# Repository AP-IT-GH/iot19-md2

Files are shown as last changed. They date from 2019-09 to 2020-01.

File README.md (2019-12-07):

# Internet of Things - Medical delivery

## Groepsleden

Jarno Cools - Project Manager, Documentating and all-round  
Imad El-Azzouzi - PCB designer, Front-end Programmer and Professional Email Sender to Mr. Luyts         
Oussama Es-Salhi - Back-end Programmer / Systems integrator  
Cristian Baba - Front-end programmer / system testing and programming

## Documentatie

[Medical Delivery Analyse](/doc/analyse.md)

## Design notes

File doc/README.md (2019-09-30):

# Medical Delivery - Documentation

## Quick links

[Medical Delivery Analyse](/doc/analyse.md)

[Explenation electrical Scheme](/doc/electrical_scheme.md)

[Power consumption](/doc/power_consumption.md)

## Datasheets

In this folder you can find all the datasheets for the used components. If refered to a datasheet there will be a link to the datasheet in the markdown file.

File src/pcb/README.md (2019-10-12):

# PCBs

## MCU module

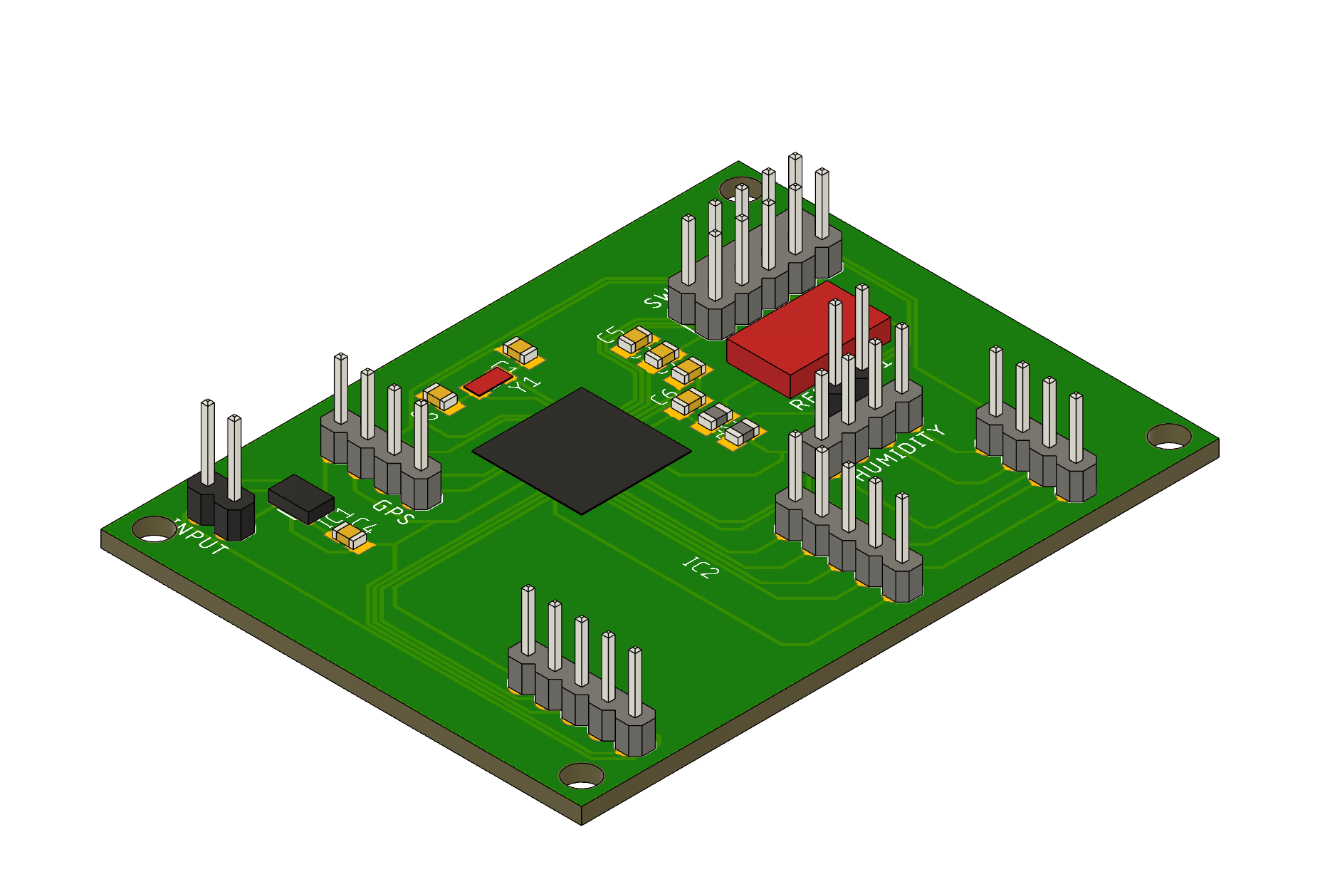
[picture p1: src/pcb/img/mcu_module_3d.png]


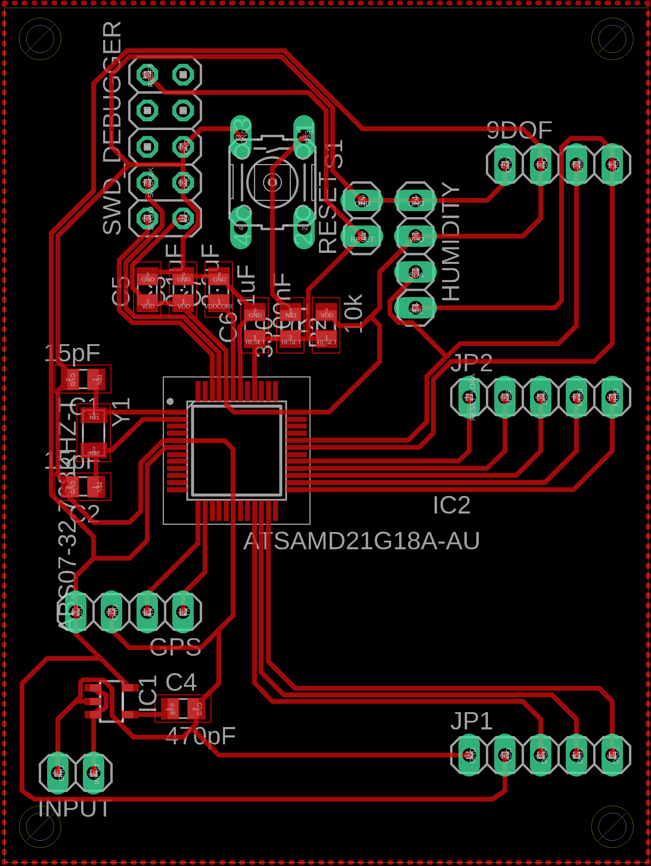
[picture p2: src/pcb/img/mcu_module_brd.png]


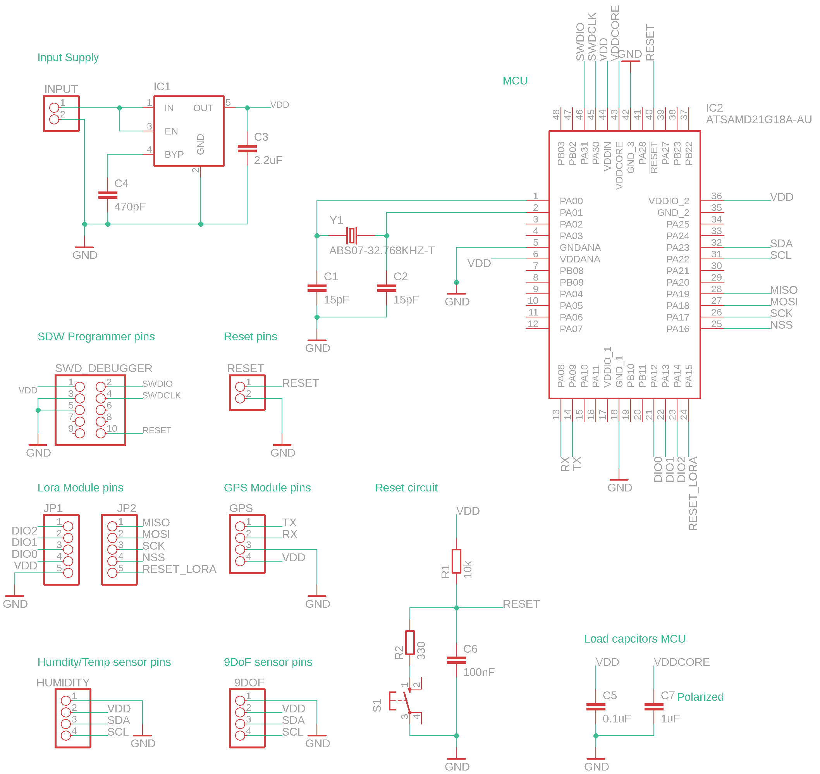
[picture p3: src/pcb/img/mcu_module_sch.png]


## LoRa module

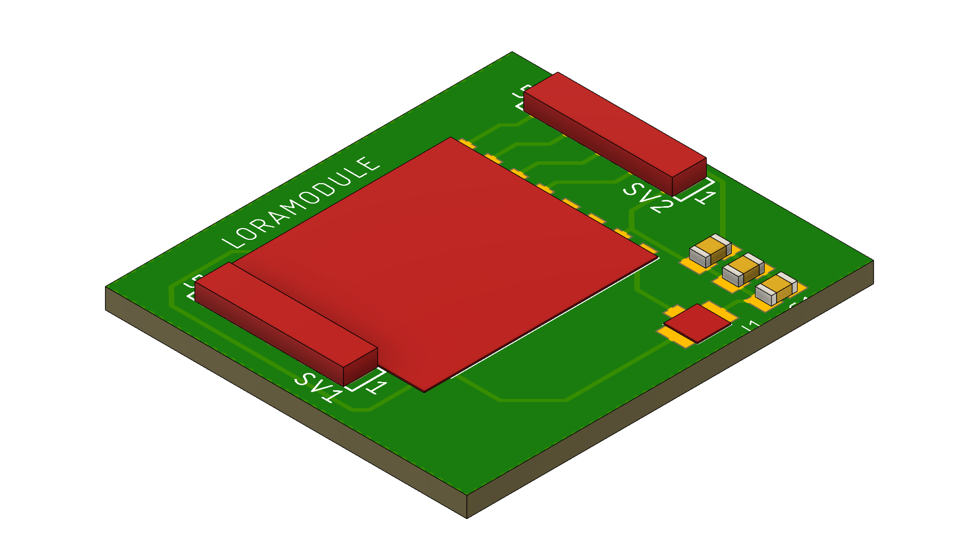
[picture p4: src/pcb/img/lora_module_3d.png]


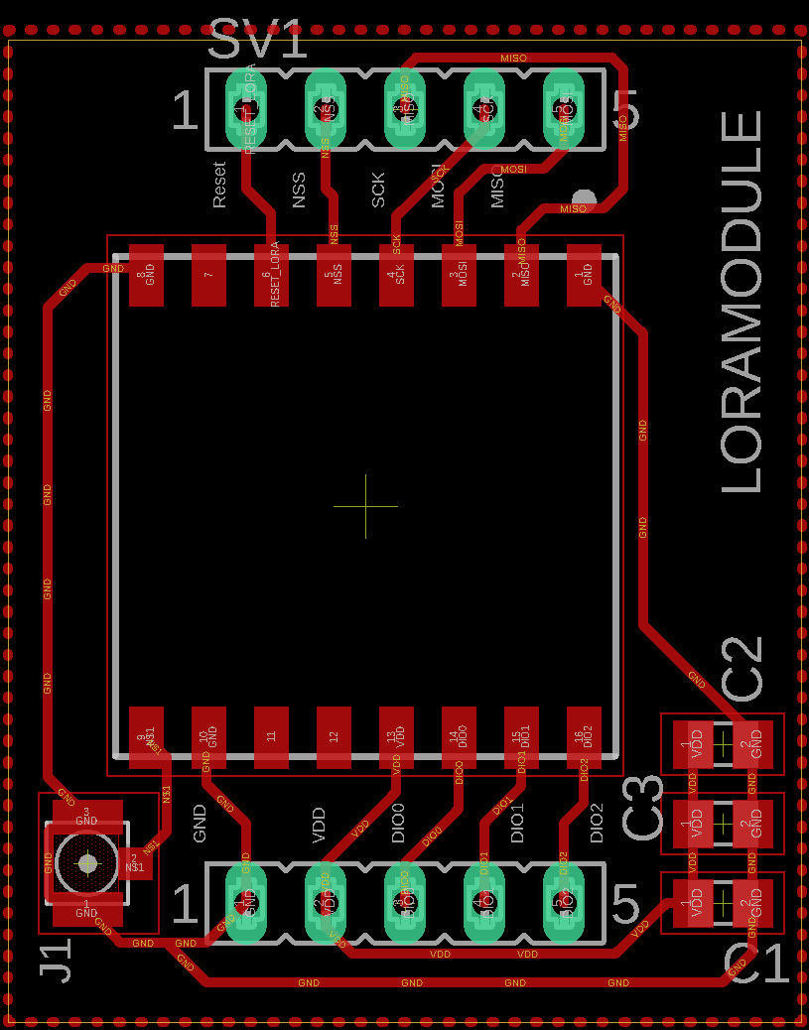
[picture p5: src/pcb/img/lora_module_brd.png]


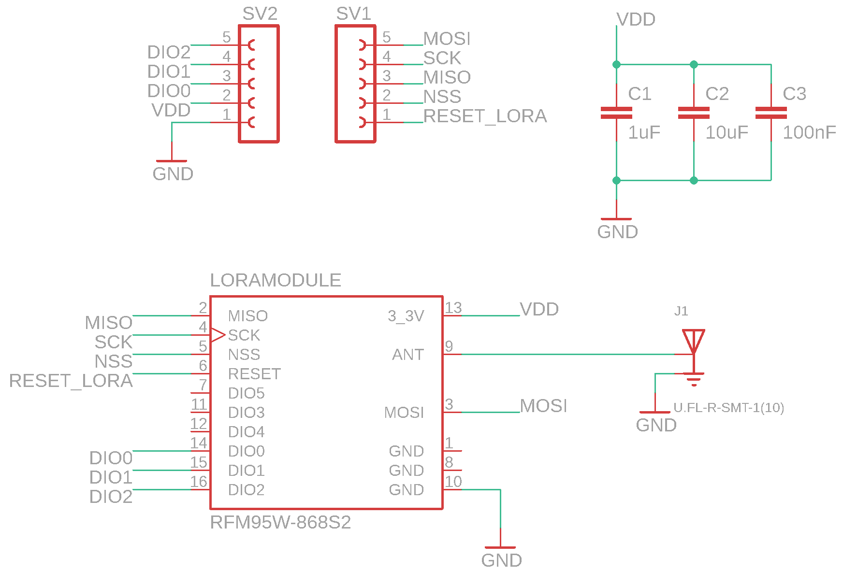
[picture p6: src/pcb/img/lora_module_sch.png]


## GPS module

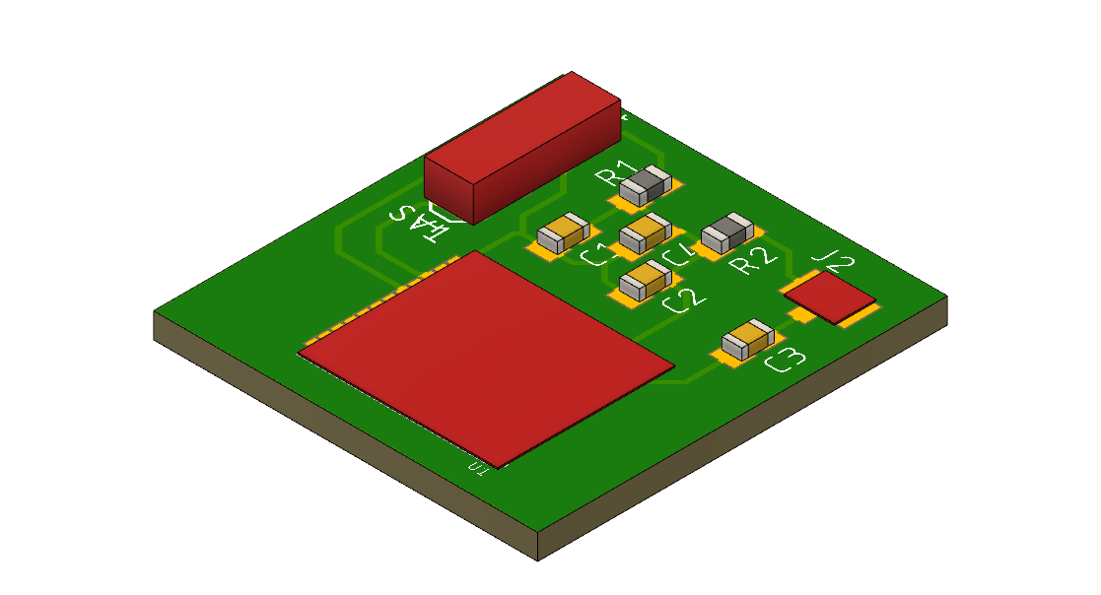
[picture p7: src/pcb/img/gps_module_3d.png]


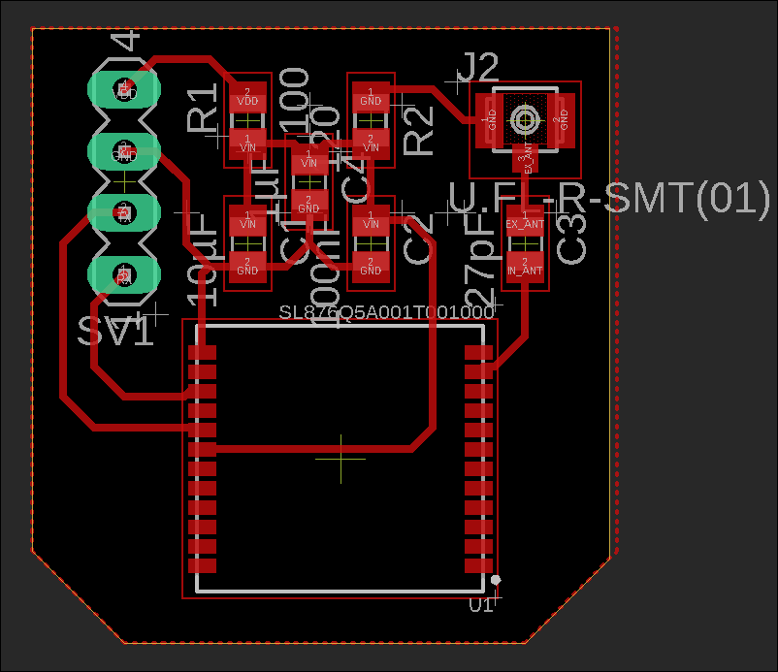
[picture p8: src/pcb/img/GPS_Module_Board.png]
Board


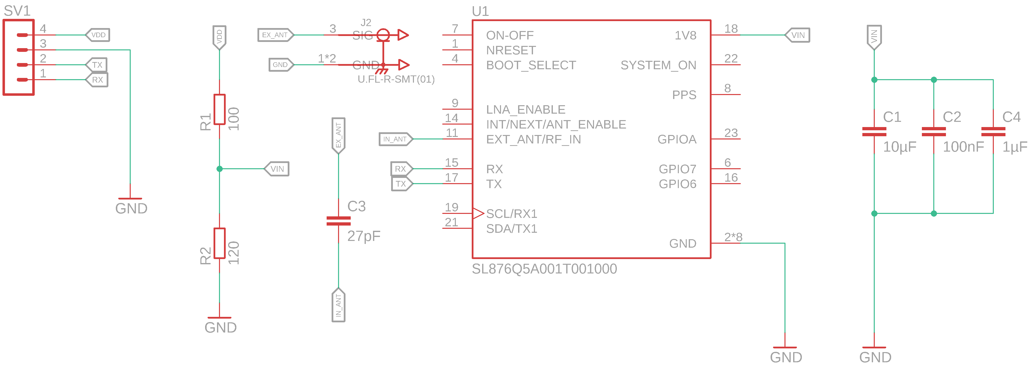
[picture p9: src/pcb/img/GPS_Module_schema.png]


## Humidity sensor

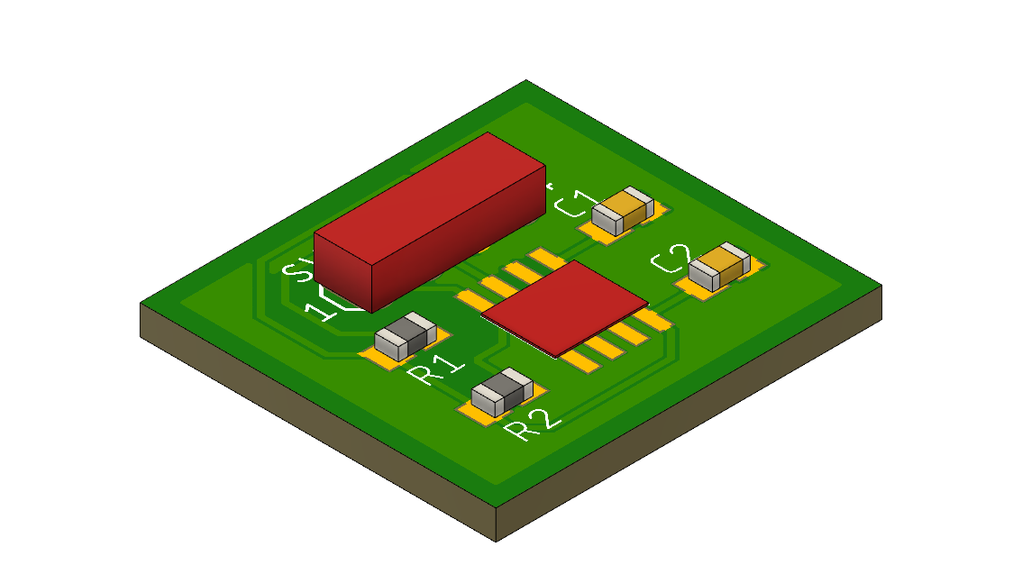
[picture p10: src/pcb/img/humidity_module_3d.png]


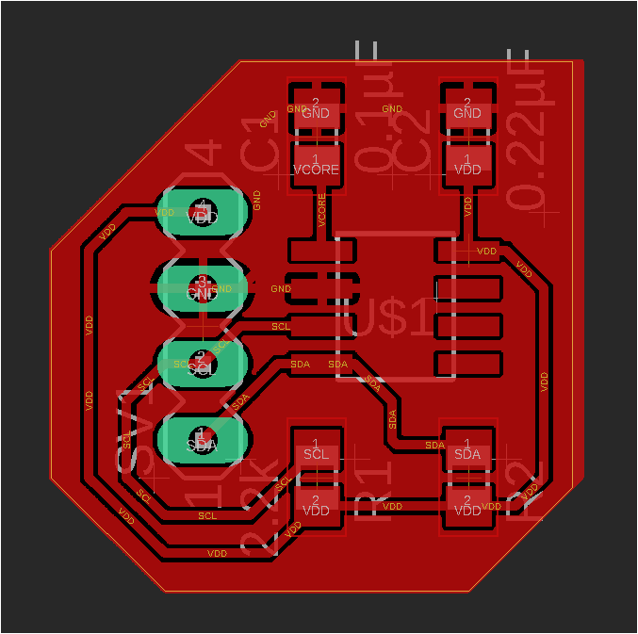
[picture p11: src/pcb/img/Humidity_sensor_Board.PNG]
Board


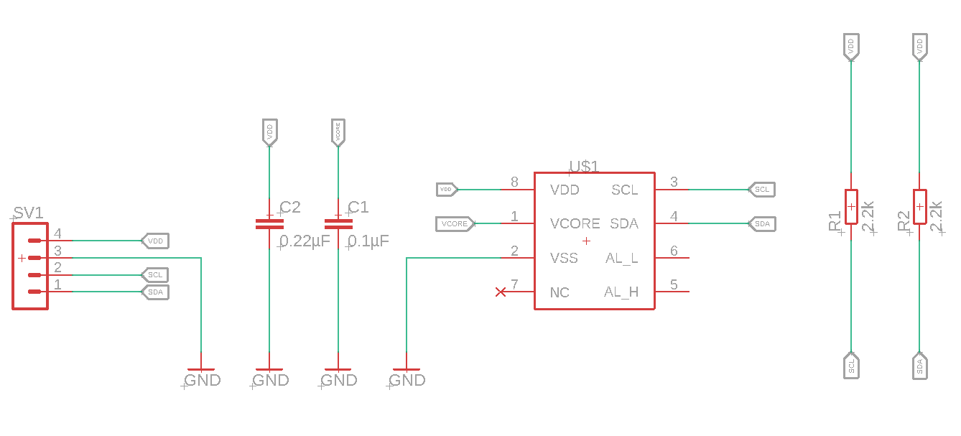
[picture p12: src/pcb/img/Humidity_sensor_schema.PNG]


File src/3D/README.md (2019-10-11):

# 3D objects

## m3_spacers_5mm.stl
This is the m3 mount for under the pcb.

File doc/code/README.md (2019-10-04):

# Code - Documentation

## Summary

The IDE used for this project is Atmel Studio 7. Programming to the MCU will be done via SWD programmer ATMEL ICE on the custom MCU module board [MCU Module](../src/pcb/img/mcu_module_3d.png). For testing code etc. before the custom board is printed and solderd the **Atmel SAMD21 XPlained PRO** board is used.

## Project init

Via the website of [Start Atmel](https://start.atmel.com/) you can initalize your project and basic settings like pin names.  
You start by choosing your IC/dev board. After choosing your IC/dev board you can add software components/drivers like for example Delay, DAC, etc. When you chose your drivers or if you didn't need any you can click on PINMUX. Here you can select a pin e.g. PA00/Pin 1 change the user label and the pin mode. After these steps you can export the project as an Atmel Project.

When exported you can import this in atmel studio as Atmel Start project. The project will have made a file **atmel_start_pins.h**.  
Here you can manually add pins as macros through (E.g. PA04):

```
#define PA04 GPIO(GPIO_PORTA, 4)
```

In the file **main.c** is where you write all you code.

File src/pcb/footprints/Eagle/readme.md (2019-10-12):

# Footprints - EAGLE

## ATSAMD21E18A-AF.lbr

Library for the ATSAMD21E.

## ATSAMD21G.lbr

Library for the ATSAMd21G.

## ABS07-32.768KHZ-T

Library for the crystal.

## S2B-PH-SM4-TB.lbr

Library for the input cable from the lithium battery.

## SL876Q5A001T001000

Library for the GPS module

## HIH6030-021-001

Library for the Humidity sensor

## U.FL-R-SMT_01_.lbr

Library for the U.FL (Male U.FL connector)

## RFM95W-868S2.lbr

Library for the LoRa module.

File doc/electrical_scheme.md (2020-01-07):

# 1. MCU Module PCB

## ATSAMD21

### Power supply

> ([Datasheet ATSAMD21](./datasheets/Atmel-42181-SAM-D21_Datasheet.pdf) p. 26, 7.2.3 and p. 1008, Table 38-1)  
> Power Supply Connection used is the typical Powering Schematic out of the datasheet.

### Externall Oscillator

> ([Datasheet ATSAMD21](./datasheets/Atmel-42181-SAM-D21_Datasheet.pdf) p. 1013, 38.6.3)

_Load capacitors calculation_

> CLtotal = (CL1 \* CL2)/(CL1+CL2) + CP  
> CL1=CL2= (CLtotal - CP) \* 2  
> CL = 12,5pF ([Datasheet ATSAMD21](./datasheets/Atmel-42181-SAM-D21_Datasheet.pdf) p.1013, Table 18-6)  
> CP = 5pF  
> CL1 = CL2 = (12,5pF - 5pF) \* 2 = 15pF

### Programmer SWD (Cortex Debug Connector)

> ([Datasheet ATSAMD21](./datasheets/Atmel-42181-SAM-D21_Datasheet.pdf) p. 1015, 38.7.1)  
> Program the MCU via SWD connection. 10 pin connector

> PA30 - SWDCLK  
> PA31 - SWDIO  
> RESET - RESET

## MIC5219-3.3YM5-TR

The voltage regulator of this project. Because MIC5219-**3.3** is used the fixed output is 3.3V.

Schematic used for the Fixed-Voltage version. ([Datasheet MIC5219](./datasheets/mic5219-3_3.pdf) p. 12, Figure 6)

### Connections to the IC

> ([Datasheet TPS735](./datasheets/tps735.pdf) p. 4, 5. Pin configuration)  
> Given all the connections for the pins, minimum and maximum values for capacitors.

### Reset circuit

The reset circuit has it's purpose to reset the MCU when the pin is triggered low. 2 header pins are added so if needed an externall reset controller could be added.

### Connections to the modules

All the sensor modules are given power through the MCU board every module has 2 extra pins for the GND and VDD(3.3V) pins.

#### LoRa Module pins

The connection between the MCU and the LoRa is SPI. Therefore the typical SPI pins are used MISO, MOSI, SCK and NSS. The reset pin from the LoRa module is connected with an DIO pin from the MCU so the MCU can reset the LoRa module. But when using the SAMD21 chips if the legacy SPI pins are not selected you'll have to create your own SPI connection [link to example](). Watch carefully in the datasheet which sercom is what en in the pinmapping of your library if the port is compatible.

> PA12 - DIO0       
> PA13 - DIO1       
> PA14 - DIO2           
> PA20 - RESET LoRa         
> PA19 - NSS        
> PA17 - SCK SERCOM1:[1] | ALT SERCOM3:[1]    
> PA16 - MOSI SERCOM1:[0] | ALT SERCOM3:[0]   
> PA18 - MISO SERCOM1:[2] | ALT SERCOM3:[2]   

#### GPS Module pins

The connection used for the GPS module is a simple serial connection (TX,RX).

> PA08 - RX  
> PA09 - TX

#### Humidity/Temp sensor pins

I2C is used between MCU and humidity sensor.

> PA22 - SCL  
> PA23 - SDA

#### 9DoF sensor pins

I2C is used between MCU and 9DoF.

> PA22 - SCL  
> PA23 - SDA

# GPS Module PCB

> ([Datasheet SE876Q5-A](./datasheets/Telit_SE876Q5-A_Datasheet.pdf))  
> ([gps_module_sch.png](../src/pcb/img/gps_module_sch.png))

### Power supply

> ([User Guide SE876Q5-A](./datasheets/Telit_SE876Q5-A_User_Guide.pdf) p. 34, 8.4.3 )  
> Capacitors are recommended with a minimum value of 10uF in parallel with a 0.1uF ceramic capacitor.

## Voltage divider

The voltage retrieved from the supply on the MCU's PCB is 3.3V. The maximum voltage of the GPS module is 1.8V. Therefore there is a voltage divider.

> Vout = I \* R2  
> I = Vin/(R1+R2)  
> Vout = Vin \* (R2/(R1 + R2))

Vin = 3.3V  
R2 = 120 Ohm and R1 = 100 Ohm

Vout = 1.8V

## SE876Q5-A

For this project is the serial port of the MCU used. So the TX from the GPS is connected to the RX from the MCU.
The TX from the MCU will be used for sending commands to the GPS.

# Lora Module RFM95W

## Antenna

An external antenna is required to transmit to and receive from the LoRa Gateway, an insulated copper wire is used with a length of 86mm.

The antenna length (L) is calculated as follow:

    c = λ x f
    L = ¼ x λ
    c = speed of light = 299792458 m/s
    λ = wavelength (m)
    f = frequency = 868000000 Hz (This frequency applies to Europe)
    L = antenna length (m)

    299792458 = λ x 868000000
    λ = 0.34538 m
    λ = 345.38 mm
    L = ¼ x λ = 86 mm (This antenna applies for Europe)

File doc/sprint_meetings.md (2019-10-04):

# Sprintmeetings

## Sprint 1

### Summarization of work

- Analyse gemaakt, elektrisch schema, componenten gekozen, release plan.
- Componenten informatie over vergaren, bedenken hoe te integreren met elkaar.
- Gekregen componenten veranderen door gekozen componenten, specificaties aanpassen in analyse en elektrisch schema aanpassen hiermee rekening houdend.

> Jarno: Analyse en documenteren. MCU PCB + elektrisch schema.  
> Imad: Analyse. Humidity en GPS PCB + schema.  
> Oussama: Analyse. MCU + LoRa module connecteren testen.  
> Cristian: Analyse. 9DoF sensor connecteren testen.

DONE:  
PCB's MCU, GPS and Humidty (Nog printen en solderen).  
First data from 9DoF.  
Able to upload simple program to MCU SAMD21 devboard.

User stories meenemen naar volgende sprint (niet helemaal af).

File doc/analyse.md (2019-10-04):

# Analyse

## Onderzoeksvraag

> Zijn producten nog bruikbaar na het transport door verschillende omstandigheden?  
> Hoe kunnen leveranciers weten dat ze tijdens transport moeten ingrijpen?  
> Wat moet er gebeuren indien producten onbruikbaar zijn geworden tijdens het transport?

## Voorstel tot oplossing

Medical delivery is een probleem in moeilijk bereikbare delen van de wereld. Er zijn veel omgevingen met schommelende temperaturen, van onder het nulpunt tot de brandende zon. Schokken tijdens het vervoeren van medische goederen kan de chemische structuur van de medicijnen aanpassen of andere pakketten onbruikbaar maken. Hierdoor bestaat er ook onzekerheid over herlevering.
Er is geen real-time informatie over de afstand en de staat van het product.

### Overzicht oplossing

Via real-time data kan men de locatie en de staat van het product nakijken. Een cross platform webapplicatie zal dit mogelijk maken. Indien een gebruiker het nodig acht om andere producten te laten brengen door een andere leverancier is dit mogelijk via de webapplicatie. De gebruiker zou de reeds bestelde producten kunnen annuleren indien deze niet meer aan de voorwaarden voldoen. Dan kan de transporteur terug gaan voor een nieuwe lading.

De mogelijkheid moet er ook zijn om alle producten onderweg op een kaart te zien, of de dozen in gebruik zijn en of deze aan het opladen zijn en waar deze gestockeerd staan. De hoeveelheid batterij resterend weergeven als je deze informatie opvraagt.

Per doos moeten er ook bepaalde specificaties ingesteld kunnen worden; bv. Hoeveel schokken kan deze doos aan, de maximum en minimum temperatuur, etc.

De leverancier moet producten kunnen kiezen welke hij meeneemt. Wanneer de leverancier een van de voorwaarden dreigt te overschrijden dient de webapplicatie op de smartphone/tablet een melding te geven zodat men hier tijdig op kan anticiperen.

#### Algemene architectuur

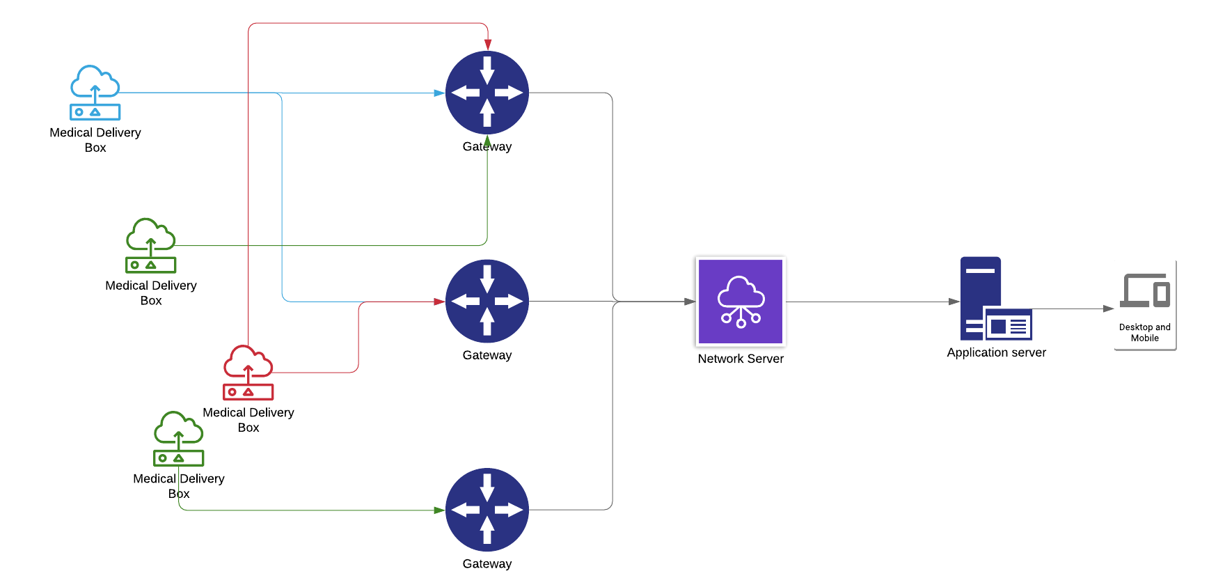
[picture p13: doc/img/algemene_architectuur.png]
Algemene architectuur

De verschillende boxen zullen als nodes werken en samen in een transportmiddel gestoken worden. Deze boxen sturen na een ingestelde tijdspanne data door indien er over de ingestelde grenzen is gegaan. De data wordt verstuurd naar LoRa Gateways. De sensor data die worden vergaard zijn oriëntatie, schokken, temperatuur, vochtigheid en positie. Aangezien het over afgelegen gebieden zou kunnen gaan waar geen LoRa gateway verbinding aanwezig zou zijn, kan er gebruikt gemaakt worden van een versterker zodat de reikwijdte vergroot wordt. De data zal gefilterd moeten worden via de end nodes zelf en enkel nodige data doorsturen.

## Marktonderzoek

| | Medicalcouriers | Hydropac | Worldcourier | Actioncourier | Zipline | TNT Healtcare section Supplies |
| --- | --- | --- | --- | --- | --- | --- |
| Sensors | ? | ? | Ambient temperature, internal temperature, light, tilt, pressureand physical shock sensors. | ? | ? | Ambient temperature and internal temperature sensors |
| Tracking | Tracking APP, Tracking center | / | GPS (Customer Resource Center (CRC) ) | Digital Log Tracking, GPS | 3D sattelite map and manual ground surveys | GPS |
| Temperature control | / | Can choose min and max of temperature | controls ambient an internal temperature | / | / | Realtime tracking of temprature |
| Communication protocol | / | / | BLE, GSM | / | SMS | / |
| App Control | Realtimedata, Dashboard | / | Realtime, monitoring | Monitoring | On-demand through a simple app, when they need it, monitoring, realtime data | Realtimedata, Monitoring |
| Transit time | / | Adjustable | / | Non-stop delivery | 30 - 45 min delivery | Sameday Delivery (ophaling en levering via de weg, na ophaling rechtstreekse levering bij de opgegeven ontvanger), Onboard courier ( zendingen die persoonlijke aandacht eisen), Air charter ( dringende zendingen ) |
| Type | Medical Courier | Insulated Shipping Systems | Medical logistics | Medical Courier serivce | Blood delivery by drone | Transport |
| Leveringen in | Washington, Oregon, Montana, Idaho, Wyoming, Californiä, Nevada, Utah, Arizona, New Mexico, Colorado, Oklahoma, Texas, Louisiana, Mississippi, Georgia, Alabama, Florida, North Carolina, Iowa, Minnesota, Wisconsin, Illinois, Michigan, Kentucky, Ohio, Indiana, Pennsylvania |  UK | Europa, North America, Asia PAcific, Latin America, Middle East, Africa |Oklahoma, Texas, Louisiana, Mississippi, Georgia, Alabama, Florida, North/South Carolina, Iowa, Minnesota, Wisconsin, Illinois, Michigan, Kentucky, Ohio, Indiana, Pennsylvania, Arkansas, Tennessee, Missouri, Virginia-West Virginia, Maryland, Delaware, New Jersey, New York, Connecticut, Massachusetts, Rhode Island, Maine, New Hampshire, Vermont | Rwanda & Ghana |Europe, Asia, Middle East, US|
| Website | [Website](https://www.medicalcouriers.com/) | [Website](https://hydropac.co.uk/#medi) | [Website](https://www.worldcourier.com/) | [Website](https://actioncourier.com) | [Website](https://flyzipline.com/) | [Website](https://common.tnt.com/express/en_xx/site/home/services/industry_sol/healthcare/pharmasafe.html) |

## Detail analyse

#### Blokdiagram

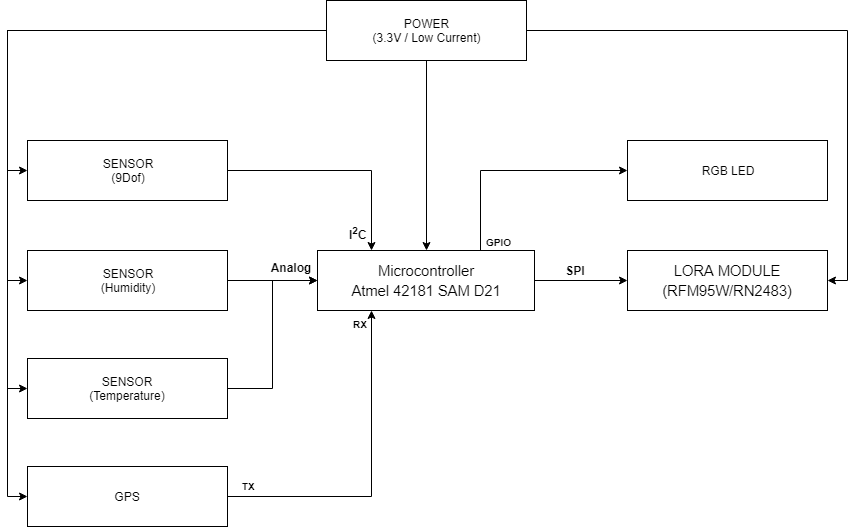
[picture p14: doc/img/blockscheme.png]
Mockup


##### Specificatietabel

| Blok | Specificatie | Min | Nominaal | Max |
| --- | --- | ----- | --- | ----- |
| Atmel SAM D21 | Werkspanning | 1.62V | | 3.63V |
| | Low-power verbruik | | <70 µA/MHz | |
| RFM95W | Werkspanning | 1.8V  | | 3.7V  |
| Lithium batterij | Spanning | | 3.7V | |
| | Capaciteit | | 2000mAh | |
| Telit SL876Q5-A GPS | Werkspanning | 1.71V | | 1.89V |
| | Stroomverbruik signal acquisition | | 85mW | |
| | Stroomverbruik tracking | | 83mW | |
| | Horizontale positie nauwkeurigheid| | 1.5m | |
| | Snelheid nauwkeurigheid | | 0.01 m/s | |
| | Richting nauwkeurigheid | | 0.01 deg | |
| HIH8120-021-001 TEMP HUM | Werkspanning | 2.3V  | 3.3 | 5.5V  |
| | Temperatuur range | -40°C | | 125°C |
| | Temperatuur nauwkeurigheid | | ±0.8 | |
| | Humidity range | 0RH | | 100RH |
| | Humidity nauwkeurigheid | | ±2.0 %RH | |
| | Sleep current | | 0.6µA | 1µA |
| | Supply current (I²C) | | 0.65mA | 1mA |
| IMU 9DOF v2.0 | Werkspanning | 2.4V  | | 3.6V  |
| MIC5219-3.3YM5-TR | Werkspanning | 2.5V  | | 12V  |
| | Uitgangspanning | | 3.3V | |
| | Stroomverbruik | 0 | | 500mA |
| | Temperatuur range | -40°C | | 125°C |
| Q13MC30610003 MC-306 | Frequency range | 20kHz | 32.768kHz  | 165kHz |
| | Laad Capaciteit | | 12.5pF | |
| | | | | |

##### Argumentatietabel

| Blok | Argumentatie | Alternatieven |
| --- | --- | --- |
| Microcontroller | Atmel SAM D21G gekozen omdat deze low power is. Heeft tot 6 Serial Communication Modules (SERCOM) dat elk geconfigureerd kunnen worden als een USART, UART, SPI of I²C. | ATmega328p |
| GPS | Er wordt gebruik gemaakt van de Telit SL876Q5-A GPS module van Telit deze module gebruikt relatief weinig vermogen (83mW - 85mW) en heeft verschillende modi die energie kunnen besparen. Ook heeft hij een hogere update rate van 10 Hz. Deze module ondersteund zowel GPS als GLONASS waardoor er meer satellieten zijn voor een nauwkeurige positie. | NEO-6M, BN-280 |
| LoRa module | RFM95W werd gekozen omdat deze aanzienlijk minder stroom verbruikt dan concurrerende modules. De hoge sensitiviteit met de +20dBm eindversterker levert een industry leading link budget op, waardoor het optimaal is voor elke toepassing die bereik of robuustheid vereist. | RN2483 |
| Temperatuur / Humidity sensor | De Honeywell 2-in-1 temperatuur- en vochtigheidssensor is nauwkeurig tot 0.8°C, 2.0 %RH en heeft een temperatuur range van -40°C tot 125°C. Door deze sensor te gebruiken wordt er pcb oppervlakte bespaart. De I2C output zorgt voor een makkelijkere integratie met de microcontroller. |  LMT87, LM35, MCP9700 |
| IMU 9DOF v2.0 | Ultra-low power, low voltage. Heeft een wide detecting range. | 9DoF Sensor Stick |

#### Elektrisch schema

Flowchart
[Elektrisch Schema](./electrical_scheme.md)
#### State Diagram

#### Flowchart

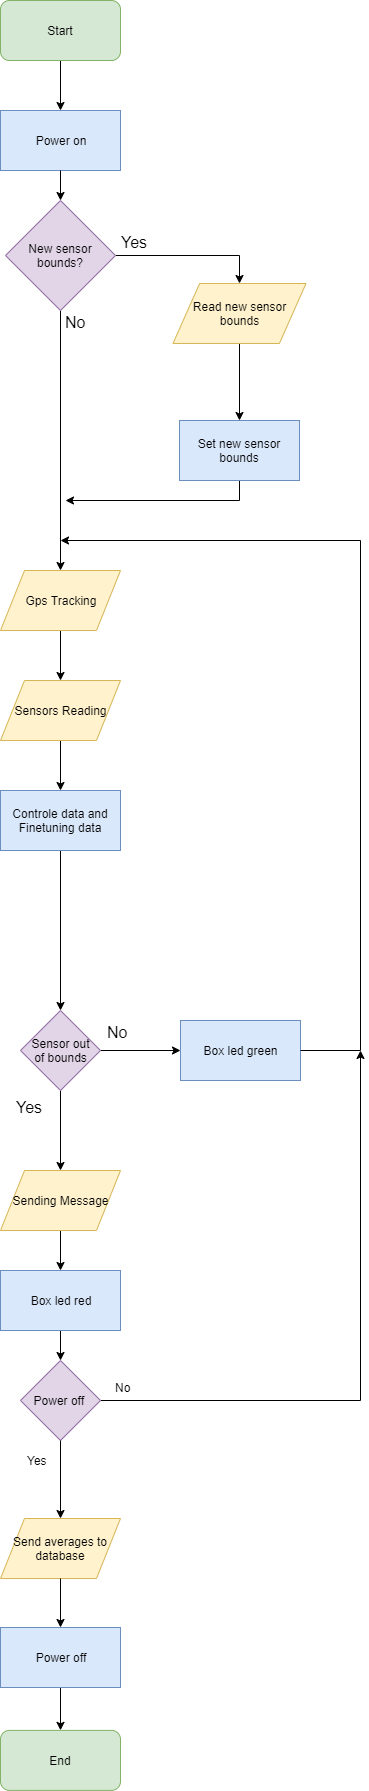
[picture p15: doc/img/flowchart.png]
Flowchart


### Front End

Mockup

### Back End

Er wordt gebruik gemaakt van firebase als "back end" dit omdat het makkelijk is om te scalen. De realtime database is ook een troef van Firebase waardoor de data in real-time wordt verstuurd naar de app of webapp wat aangenamer is voor de eindgbruiker.

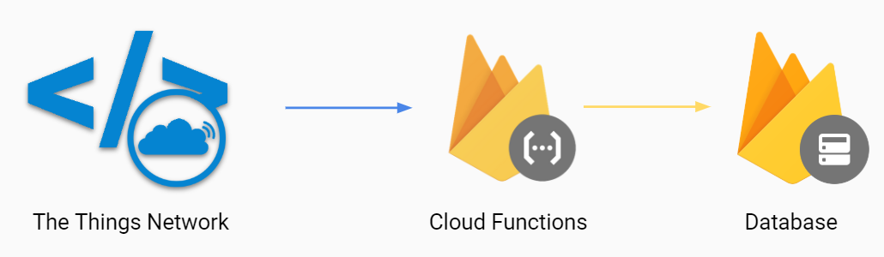
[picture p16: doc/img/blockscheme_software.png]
Software blockscheme


#### Database Model

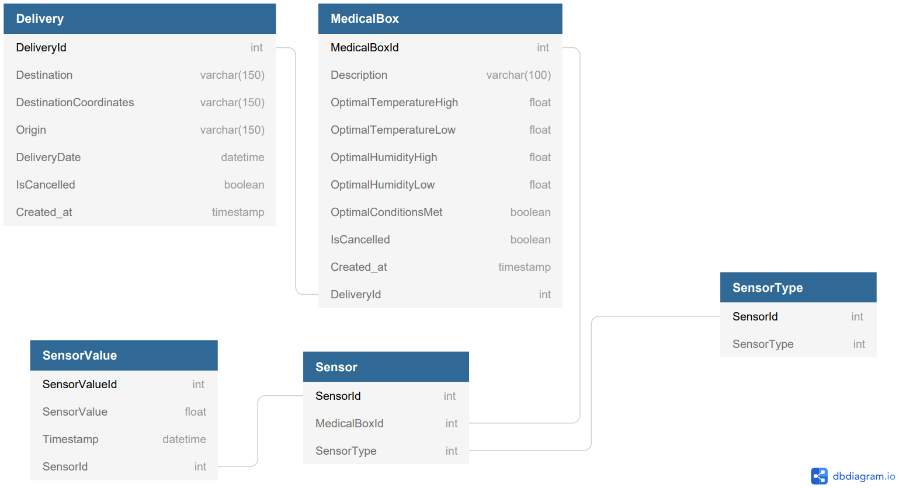
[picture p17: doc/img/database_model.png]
Database Model


## Niet functionele analyse

## Release plan

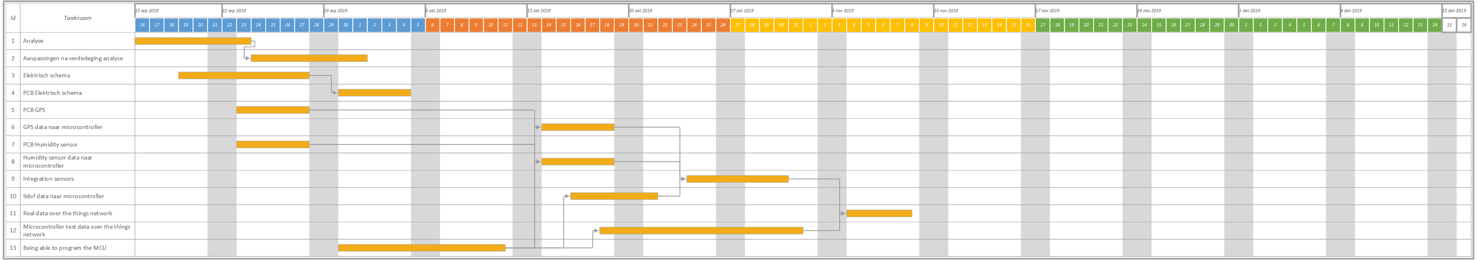
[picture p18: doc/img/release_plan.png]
Release plan sprint 1-2


## Inventarisatie Hardware

- Atmel SAM D21E - Microcontroller
- RFM95W - LoRa Module
- Telit SL876Q5-A - GPS Module
- HIH8120-021-001 - Temperature/Humidity sensor
- IMU 9DOF v2.0 - 9DoF
- MIC5219-3.3YM5-TR - Voltage regulator
- Lithium battery

[Bill of materials](./Bill_of_materials.pdf)

## Inventarisatie software

- AtmelStudio
- Angular
- Firebase

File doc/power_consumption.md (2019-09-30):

# Power consumption

De engerie die verbruikt wordt door alle componenten samen zou door de power supply een x-aantal uur geleverd moeten kunnen worden. Het berekenen van de consumptie gaat als volgt.
Vermogen W (**P = U \* I**) van dit vermogen wordt Wh genomen (**Wh = W \* h**). Hierna wordt er mAh berekend **mAh = 1000 \* Wh / V**. Deze mAh is nodig omdat batterij capaciteit in mAh is.

### Atmel SAMD21E

> (Datasheet Atmel SAMD21)  
> When the CPU is running a Fibonacci algorithm at 3.3V (25°C). The max. power consumption is 4.6mA.

- P = U \* I => P = 3.3V \* 4.6mA = 0.01518W
- Wh = 0.01518Wh (t = 1h)
- mAh = 1000 \* 0.1518Wh/3.3V = 20mAh

### HONEYWELL - HIH8120-021-001 TEMP HUM

> (HONEYWELL DATASHEET)
> -Via I2C is het verbruik gewoonlijk 0.65 mA

- P = U \* I => P = 3.3V \* 0.65mA = 0.002145W
- Wh = 0,002145 Wh
- mAh = 1000 \* 0.002145 Wh/3.3V = 0.65mAh

### Telit SL876Q5-A GPS

> (Telit Datasheet )

- Current consumption: ( GPS+GLO)
- Acquisition: 85mW
- Tracking: 83 mW

> Low power modes

- Hibernate: 69 uW
- SG1 mode: 47-56mW
- HPR mode: 24-27mW

- Verbruik = 83 Mwh
- wh = 0.083Wh (watt hour)
- mAh = 1000 \* 0.083Wh/3.3V = 25.15mAh

### Voltage regulator - TPS73533DRVT

> TPS73533DRVT Datasheet

- Verbruik 45-μA (typical)
- P = U \* I => P = 3.3V \* 45μA = 0.0001485‬W
- wh = 0.0001485‬Wh
- mAh = 1000 \* 0.0001485‬Wh /3.3V = 0.045‬mAh

### Crystal Oscillator

> (Datasheet)

- Verbruik +- 100µW
- Wh = 0.0001 Wh
- mAh = 1000 \* 0.0001‬Wh /3.3V = +- 0.33mAh

### LMT87

> (Datasheet)

- Verbruik 6.6μA
- P = U \* I => P = 3.3V \* 6.6μA = ‬0.00002178W
- Wh = 0.00002178 Wh
- mAh = 1000 \* 0.00002178 Wh /3.3V = 0.066mAh

### IMU 9DoF v2.0

> (Datasheet)

- 9-axis (no DMP), 1 kHz gyro ODR, 4 kHz accel ODR, 8 Hz mag. repetition rate
- 4,9 mA
- P = U \* I => P = 3.3V \* 0.049A = 0,1617‬W
- Wh = 0.1617‬ Wh
- mAh = 1000 \* 0.1617‬ Wh /3.3V = 49 mAh

### RFM95W

> (Datasheet RFM95 p.13 2.4.1)  
> IDDT supply current when transmitting is 120mA.

- P = U \* I => P = 3.3V \* 120mA = 27,5W
- Wh = 0.01518Wh (t = 1h)
- mAh = 1000 \* 0.1518Wh/3.3V = 20mAh

## Totale verbruik

- mAh(totaal) = 20mAh + 0.65mAh + 25.15mAh + 0.045mAh + 0.33mAh + 49mAh + 20mAh = 115.175mAh

Het aantal uren voordat de batterij leeg is:

- Capaciteit / Totale Verbruik => 2000mAh / 115.175mAh = 17.36 Uur

_\*Opmerking: In deze berekening is er geen rekening gehouden met het feit dat de LoRa module niet continu gaat uitzenden en de mogelijke optimalisatie van het verbruik van de verschillende componenten. Dit betekent dat het totale verbruik behoorlijk lager zal liggen._

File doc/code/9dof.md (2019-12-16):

# LoRa The Things Network Code Documentation

## Getting started

The 9DoF stick is connected via I2C to the microcontroller.

To install this library:

- Install it using the Arduino Library manager ("Sketch" -> "Include Library" -> "Manage Libraries...")
- download a zipfile from github using the "Download ZIP" button and install it using the IDE ("Sketch" -> "Include Library" -> "Add .ZIP Library..."
- clone the git repository into your sketchbook/libraries folder

  [Download Link LSM9DS1 Library](https://github.com/sparkfun/SparkFun_LSM9DS1_Arduino_Library/archive/master.zip)

## Sketch

In __LSM9DS1_Basic_I2C.ino__ you can see an example setup of some code that prints the 9DoF stick data.

As an example ```imu.calcAccel(imu.az)``` this shows the amount of force when moving up or down. This gives a digit back in the sketch they refer to it as G. In the graph you can see that we there were somet tests done. The peaks going up over 1.5 are forces going upwards (9DoF stick moving upwards). The others peaks going down under 0.5 are forces going downwards (9DoF stick moving downwards). In resting position the G-force is around 1 (G-force from the earth around 9.8m/s^2).

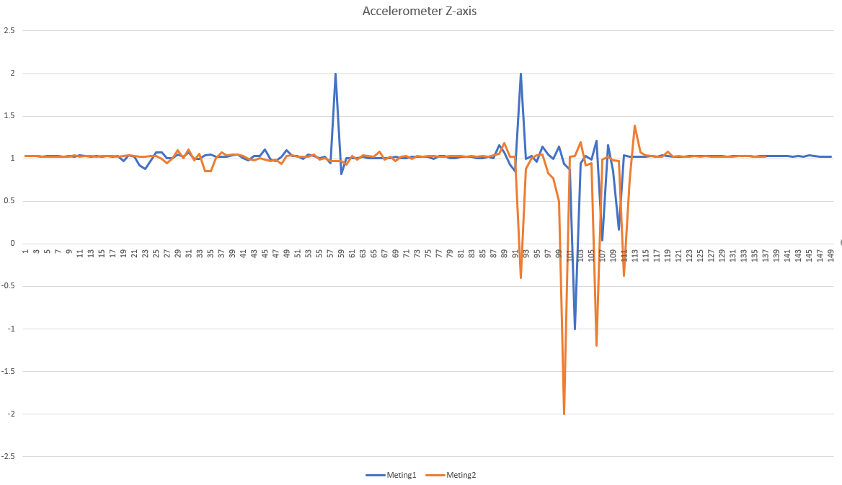
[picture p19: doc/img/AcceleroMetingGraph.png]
Accelro graph


## Integration LoRaWAN & 9DoF

For the integrations there were chosen some set boundaries. We send every out of boundaries a payload over the LoRa network. The payload was the highest/lowest value of the peak.

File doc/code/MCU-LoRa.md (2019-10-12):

# LoRa The Things Network Code Documentation

## Getting started

To communicate with the LoRaWAN network via the RFM95W module the "arduino-lmic" library is used.

To install this library:

- Install it using the Arduino Library manager ("Sketch" -> "Include Library" -> "Manage Libraries...")
- download a zipfile from github using the "Download ZIP" button and install it using the IDE ("Sketch" -> "Include Library" -> "Add .ZIP Library..."
- clone the git repository into your sketchbook/libraries folder

  [Link to arduino-lmic github repo](https://github.com/matthijskooijman/arduino-lmic)

## Library configuration

Open this file in your code editor: C:\Users\\\<username>\\Documents\Arduino\libraries\arduino-lmic-master\src\lmic\config.h

Make the following changes and save:

- set: #define CFG_eu868 1 (EU only)
- set: #define CFG_sx1276_radio 1
- set: #define LMIC_DEBUG_LEVEL 2 and #define LMIC_FAILURE_TO Serial
- Uncomment line: #define DISABLE_PING
- Uncomment line: #define DISABLE_BEACONS

## Using ttn-abp example sketch

To test the module and TTN integration an example sketch can be used.  
Load this sketch up in the arduino IDE by going to "File" -> "Examples" -> "LMIC-Arduino" -> ttn-abp (Activation-by-personalisation)

There are a couple things that need to be changed before uploading the sketch.

Copy the Network Session Key in constant variable:  
&nbsp; &nbsp; static const PROGMEM u1_t NWKSKEY[16] = { 0x1F, 0x42, 0x97, 0x73, 0xAE, 0xEA, 0xDA, 0xE8, 0xD4, 0xEE, 0x45, 0xF7, 0x54, 0xD4, 0xAE, 0x57 };

Copy the App Session Key in constant variable:  
&nbsp; &nbsp; static const u1_t PROGMEM APPSKEY[16] = { 0x96, 0x74, 0x6C, 0x57, 0xD8, 0xE3, 0xB1, 0xD6, 0x3A, 0x04, 0x83, 0x04, 0xC4, 0x56, 0x8D, 0x36 };

Copy the Device Address in constant variable:  
&nbsp; &nbsp; static const u4_t DEVADDR = 0x43984832;

Change the pinmap object:  
const lmic_pinmap lmic_pins = {  
&nbsp; &nbsp; &nbsp; &nbsp; .nss = 10,  
&nbsp; &nbsp; &nbsp; &nbsp; .rxtx = LMIC_UNUSED_PIN,  
&nbsp; &nbsp; &nbsp; &nbsp; .rst = 5,  
&nbsp; &nbsp; &nbsp; &nbsp; .dio = {2, 3, LMIC_UNUSED_PIN},  
};

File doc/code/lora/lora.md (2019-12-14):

# LoRa the things network
## LoRa RFM95W library

In dit project is er gebruik gemaakt van de arduino-lmic [library](https://github.com/matthijskooijman/arduino-lmic).

Echter omdat er gewerkt werd met een SAMD21 en de legacy SPI pins niet gekozen werden was het noodzakelijk om een SPIClass in te stellen voor deze poorten. Dit werd in de library zelf aangepast.

Aangepaste library: [LMIC - SERCOM](./arduino-lmic-aangepast.zip).

```
SPIClass SPI3(&sercom1, 10, 13, 11, SPI_PAD_0_SCK_1, SERCOM_RX_PAD_2);
```

```
    // Dit stuk code zou in een nieuwe methode kunnen gebeuren, dit is in de hal_spi_init() methode in de library geplaatst. 
    pinPeripheral(10, PIO_SERCOM);
    pinPeripheral(11, PIO_SERCOM);
    pinPeripheral(13, PIO_SERCOM);
```
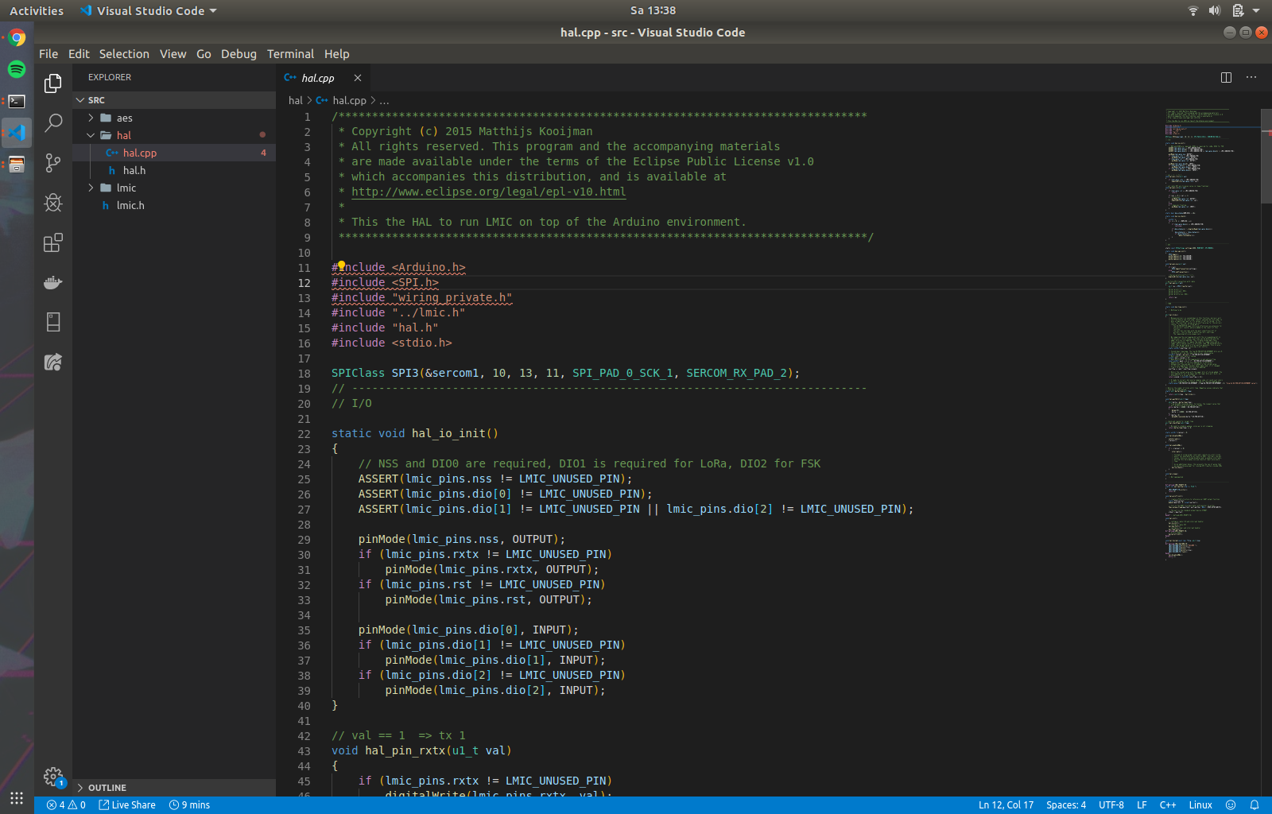
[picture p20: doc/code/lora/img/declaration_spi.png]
SPI Class


Eensgelijks moest de juiste SPIClass aangeroepen worden dus in plaats van *"SPI.begin()"* werd dit vervangen door *"SPI3.begin()"*.

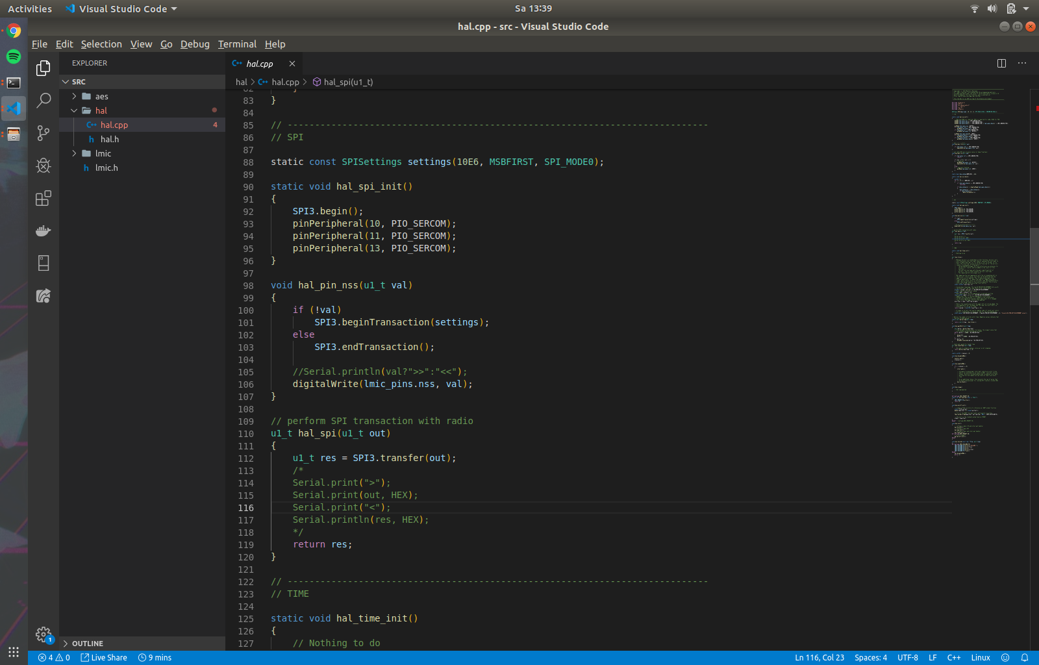
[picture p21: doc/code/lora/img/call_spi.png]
SPI calls


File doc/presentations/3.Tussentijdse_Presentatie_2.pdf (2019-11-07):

# Medical Delivery

# IoT - Tussentijdse presentatie 2

# Burndown chart

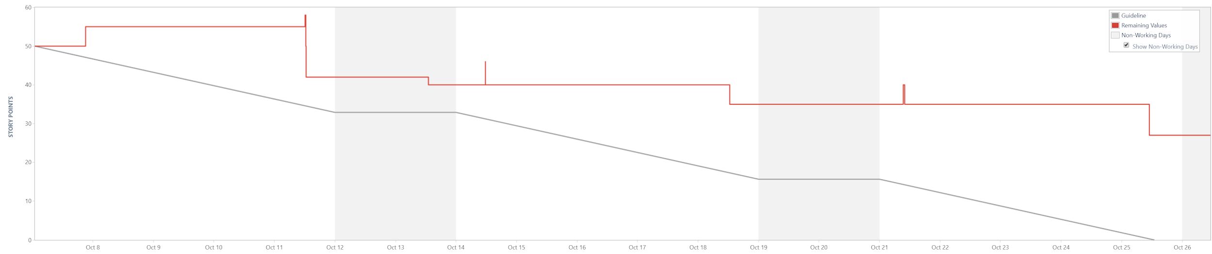
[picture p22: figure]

### User story done MD2-8

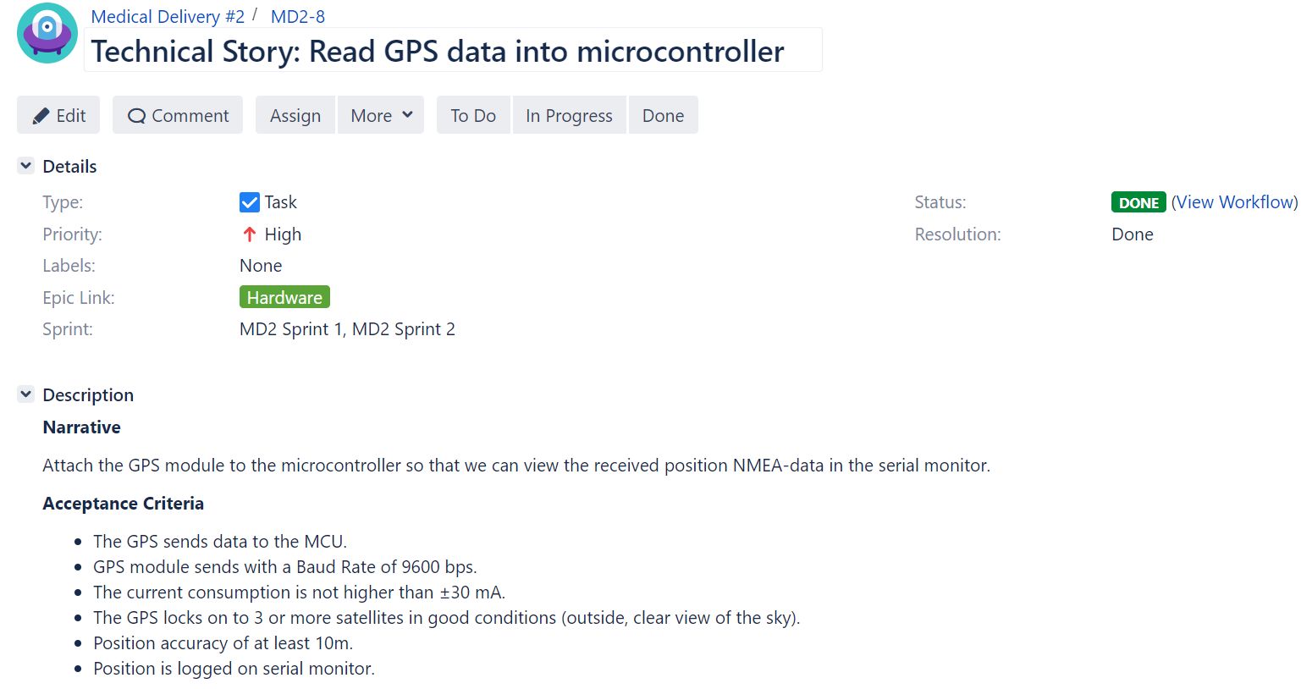
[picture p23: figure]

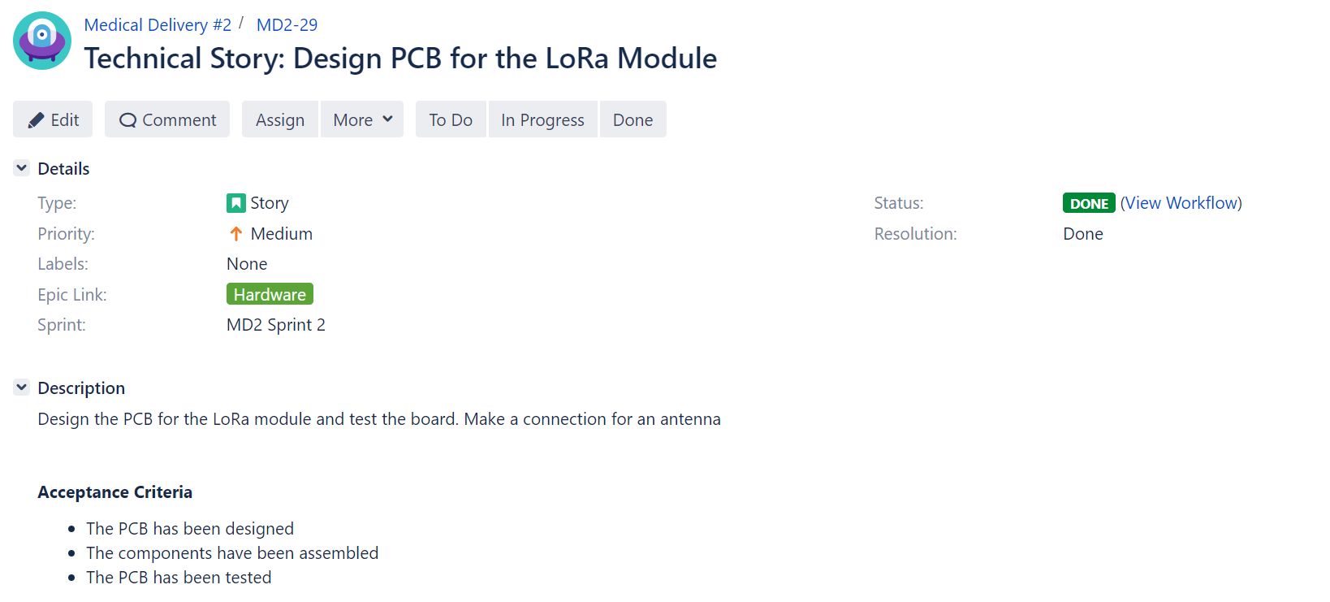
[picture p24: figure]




### Stories mee te nemen naar volgende sprint


Integration belangrijk

### Updates in analyse

- 9DoF documentation


### Jarno

- LoRa module pcb gesoldeerd en getest
- Integratie 9DoF - LoRa module
- Integratie GPS en 9DoF met LoRa module (Oussama)
- Tijdelijke breakout board voor humidity sensor gemaakt

### Imad


Update GPS module schema:

Temperature/Humidity sensor uitlezen

### Cristian


- 9DoF sensor getest
- Map

OpenLayers Api

### Oussama

- Verbinding GPS - MCU
- Integratie GPS - LoRa module
- Integratie GPS en 9DoF met LoRa module (Jarno)

### Openstaande design vragen


?

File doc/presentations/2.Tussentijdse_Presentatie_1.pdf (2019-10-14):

# Medical Delivery

## IoT - Tussentijdse presentatie

# Sprint 1 - Burndown Chart


# Sprint 2 - Burndown Chart


Sprint 2 - User story done MD2-14


Sprint 2 - User story done MD2-17


# In Progress


User stories meer opdelen in kleinere user stories. Rekening houden met afprinten pcb.

# Updates in Analyse

- Added power consumption document
- Added code documentation
- Added sprint meetings doc
- Updated electrical scheme
- Updated flowchart
- Added regio’s in tabel marktonderzoek

Verdeling taken - Release plan


# Presteerde werk

- Analyse geupdate telkens bij aanpassingen
- Documenteren van code
- Denken over integreren van componenten met elkaar
- Componenten dat verkrijgbaar waren in het labo aanpassen in schema’s en pcb designs


Jarno


Imad


Cristian


Oussama

TODO


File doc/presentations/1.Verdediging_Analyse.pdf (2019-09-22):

# Medical Delivery

## IoT

Zijn producten nog bruikbaar na het transport door verschillende omstandigheden?
Hoe kunnen leveranciers weten dat ze tijdens transport moeten ingrijpen?
Wat moet er gebeuren indien producten onbruikbaar zijn geworden tijdens het transport?

Algemene Architectuur


LoRa WAN


Marktonderzoek

# Detail Analyse

Blokschema


# Componenten

# Microcontroller

## Atmel SAM D21G


“The Atmel® | SMART SAM D21 is a series of low-power microcontrollers using the 32-bit ARM® Cortex®-M0+ processor, and ranging from 32-
to 64-pins.” - Datasheet ATMEL SAM D21

# LoRa Module

## RFM95W


Werkspanning: 1.8V-3.7V

Low power


# GPS Module

## MTK339


Low power

10 posities per second

Ingebouwde antenne

# Temperatuursensor

## LMT87


Gemiddelde nauwkeurigheid 0.5℃

Bereik van -50℃ to 150℃

# Humidity sensor

Capacitive, Resistance and Thermal


Elektrisch schema


# Diagrammen

State diagram


Flowchart


# Mock up


Release plan


# Software

Software; AtmelStudio; Firebase; Angular

The Things Network | Cloud Functions | Database

Database Model


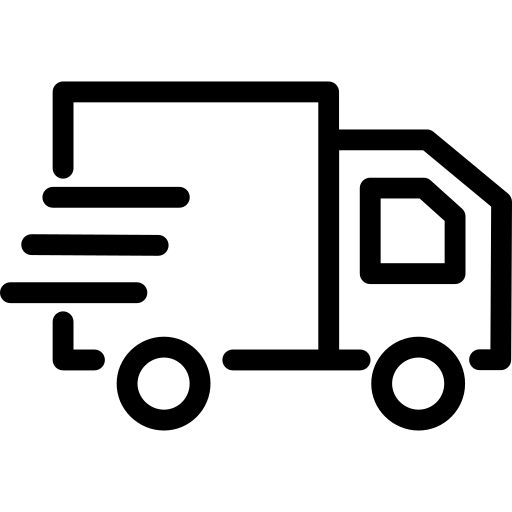
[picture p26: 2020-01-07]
src/Angular/medicaldelivery/src/assets/delivery-truck.png

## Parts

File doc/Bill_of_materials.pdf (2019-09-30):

Product name | Price | Link
HONEYWELL - HIH8120-021-001 TEMP HUM | €8,42 | Farnell (https://be.farnell.com/honeywell/hih8120-021-001/humidity-temp-sensor-digital-sip/dp/2356756)
ATSAMD21E18A-AU - MCU | €2,64 | Farnell (https://be.farnell.com/microchip/atsamd21e18a-au/mcu-32bit-cortex-m0-48mhz-tqfp/dp/2409244)
Telit SL876Q5-A GPS | ? | ?
Voltage regulator - TPS73533DRVT | Niet op voorhaad bij Farnell | Farnell (https://be.farnell.com/texas-instruments/tps73533drvt/ic-ldo-volt-reg-3-3v-0-5a-son/dp/1706085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) | Digikey 1,34 euro (https://www.digikey.be/product-detail/nl/texas-instruments/TPS73533DRVT/296-24289-1-ND/2039713) | (perfecte specs)
S2B-PH-SM4 - wire to board connector | €0,504 voor 10 | Farnell (https://be.farnell.com/jst-japan-solderless-terminals/s2b-ph-sm4-tb-lf-sn/connector-header-smt-r-a-2mm-2way/dp/9492615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)
Crystal | €0,80 | Farnell (https://be.farnell.com/epson/q13mc30610003-mc-306-32-768khz-12-5pf/crystal-mc-306-32-768-khz-12-5/dp/1216208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)
RFM95W - LoRa module | €22,73 | Farnell (https://be.farnell.com/hoperf/rfm95w-868s2/transceiver-868mhz-fsk-ook/dp/2759294?st=Lora%20module)
Lithium battery | €23,03 | Farnell (https://be.farnell.com/bak/103456a-1s-3m/battery-lithium-ion-3-7v-2050mah/dp/2401856?st=lithium%20battery)

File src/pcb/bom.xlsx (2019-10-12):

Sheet: Handleiding
 |  | Hoe gebruik je deze excelsheet |  | Mogelijk leveranciers
 |  | * Vertrek vanuit je schema en PCB ontwerp |  | (Ga de volgorde af.)
 |  | * Lijst alle componenten op geeft deze een beknopte beschrijving (Niet op dit werkblad) | 1 | https://be.farnell.com
 |  | * Kijk na of de component beschikbaar is in het labo | 2 | https://www.tinytronics.nl/shop/nl
 |  | * Is deze niet beschikbaar kijk dan na of er alternatief ter beschikking is in het labo | 3 | https://www.digikey.be/
 |  | * Als er alternatief beschikbaar is kleur dan de lijn in de BOM in het oranje | 4 | https://www.rs-components.com/index.html
 |  | * Noteer het alternatief onder de originele component | 5 | https://www.conrad.be
 |  | * Noteer vooor elke component ook de correcte package (haal deze uit de datasheet)
 |  | * Zoek dan de component op bij de mogelijke leveranciers (Let op de stock)
 |  | * Vervolledig de informatie
 |  | * Heb je meerdere PCBs maak een extra werkblad aan
Referentie schema | # Stuks | Beschrijving component | Beschikbaar in het labo | Packaging | Prijs/stuk | Fabrikant | SKU Fabrikant | Leverancier | SKU Leverancier | URL Leverancier
R1 | 2 | 100k Weerstand | x | TH | 0.05 | Multicomp | MCCFR0W8J0104A20 | Farnell | 1128068 | https://be.farnell.com/multicomp/mccfr0w8j0104a20/carbon-film-resistor-100kohm-125mw/dp/1128068
U1 | 1 | LD1117 LDO 3,3V | / | SOT-223
U1 | 1 | MIC5219 LDO 3,3V | x | SOT-23 | 0.81 | Microchip | MIC5219-3.3YM5-TR | Farnell | 2510252 | https://be.farnell.com/microchip/mic5219-3-3ym5-tr/ldo-0-5vdo-0-5a-3-3v-1-5sot23/dp/2510252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

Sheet: PCB MCU
Referentie schema | # Stuks | Beschrijving component | Packaging | Prijs/stuk | Fabrikant | SKU Fabrikant | Leverancier | SKU Leverancier | URL Leverancier
Y1 | 1 | 32.768 kHz crystal | SMD | 0.745 | ABRACON | ABS07-32.768KHZ-T | Farnell | 2101347 | https://be.farnell.com/abracon/abs07-32-768khz-t/crystal-32-768khz-12-5pf-smd/dp/2101347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
C1, C2 | 2 | 15 pF Capacitors | SMD 0805 | 0.0683 | KEMET | C0805C150J5GACTU | Farnell | 1414668 | https://be.farnell.com/kemet/c0805c150j5gactu/cap-15pf-50v-5-c0g-np0-0805/dp/1414668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
IC1 | 1 | MIC5219-3.3YM5-TR | SOT-23-5 | 0.808 | MICROCHIP | MIC5219-3.3YM5-TR | Farnell | 2510252 | https://be.farnell.com/microchip/mic5219-3-3ym5-tr/ldo-0-5vdo-0-5a-3-3v-1-5sot23/dp/2510252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
C3 | 1 | 2.2uF Capacitor | SMD 0805 | 0.281 | TAIYO YUDEN | UMK212BB7225KG-T | Farnell | 2779058 | https://be.farnell.com/taiyo-yuden/umk212bb7225kg-t/capacitor-mlcc-x7r-2-2uf-50v-0805/dp/2779058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
C4 | 2 | 470pF Capacitor | SMD 0805 | 0.0617 | MULTICOMP | MC0805B471M101CT | Farnell | 1708840 | https://be.farnell.com/multicomp/mc0805b471m101ct/ceramic-capacitor-470pf-100v-x7r/dp/1708840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
R1 | 1 | 10kOhm resistor | SMD 0805 | 0.0272 | VISHAY (https://be.farnell.com/b/vishay) | CRCW080510K0FKEA | Farnell | 1469856RL | https://be.farnell.com/vishay/crcw080510k0fkea/res-10k-1-0-125w-0805-thick-film/dp/1469856RL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
R2 | 1 | 330Ohm resistor | SMD 0805 | 0.0308 | VISHAY (https://be.farnell.com/b/vishay) | CRCW0805330RFKEA | Farnell | 1469918 | https://be.farnell.com/vishay/crcw0805330rfkea/res-330r-1-0-125w-0805-thick-film/dp/1469918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
C6, C5 | 1 | 100 nF capacitor/ 0.1uF | SMD 0805 | 0.281 | AVX | 08051C104JAT2A | Farnell | 2332715RL | https://be.farnell.com/avx/08051c104jat2a/cap-0-1-f-100v-5-x7r-0805/dp/2332715RL?st=0805%20100nF
C7 | 1 | 1 uF capacitor | SMD 0805 | 0.36 | AVX | 08053C105K4Z2A | Farnell | 1833845 | https://be.farnell.com/avx/08053c105k4z2a/cap-1-f-25v-10-x7r-0805/dp/1833845?st=0805%201uF
S1 | 1 | SMD switch | SMD | 0.411 | OMRON | B3FS-1000 | Farnell | 3121161 | https://be.farnell.com/omron/b3fs-1000/tactile-switch-0-05a-24vdc-illum/dp/3121161?st=smd%20switch
IC2 | 1 | ATSAMD21G18A-AU | 48-pin TQFP | 2.79 | MICROCHIP | ATSAMD21G18A-AU | Farnell | 2409248 | https://be.farnell.com/microchip/atsamd21g18a-au/mcu-32bit-cortex-m0-48mhz-tqfp/dp/2409248?st=ATSAMD21G

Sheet: PCB LoRa module
Referentie schema | # Stuks | Beschrijving component | Packaging | Prijs/stuk | Fabrikant | SKU Fabrikant | Leverancier | SKU Leverancier | URL Leverancier
C3 | 1 | 100 nF capacitor/ 0.1uF | SMD 0805 | 0.281 | AVX | 08051C104JAT2A | Farnell | 2332715RL | https://be.farnell.com/avx/08051c104jat2a/cap-0-1-f-100v-5-x7r-0805/dp/2332715RL?st=0805%20100nF
C1 | 1 | 1 uF capacitor | SMD 0805 | 0.36 | AVX | 08053C105K4Z2A | Farnell | 1833845 | https://be.farnell.com/avx/08053c105k4z2a/cap-1-f-25v-10-x7r-0805/dp/1833845?st=0805%201uF
C2 | 1 | 10 uF capacitor | SMD 0805 | 0.59 | AVX | 08053D106KAT2A | Farnell | 1867958 | https://be.farnell.com/avx/08053d106kat2a/cap-10-f-25v-10-x5r-0805/dp/1867958?st=0805%2010uF
LORAMODULE | 1 | RFM95W-868S2 | SMD | 22.73 | HOPERF | RFM95W-868S2 | Farnell | 2759294 | https://be.farnell.com/hoperf/rfm95w-868s2/transceiver-868mhz-fsk-ook/dp/2759294?st=RFm95W
J1 | 1 | Antenna pin |  | 0.97 | HIROSE(HRS) | U.FL-R-SMT(01) | Farnell | 3908021 | https://be.farnell.com/hirose-hrs/u-fl-r-smt-01/rf-coaxial-u-fl-straight-jack/dp/3908021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

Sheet: PCB GPS module
Referentie schema | # Stuks | Beschrijving component | Packaging | Prijs/stuk | Fabrikant | SKU Fabrikant | Leverancier | SKU Leverancier | URL Leverancier
R1 | 1 | 100 Ω weerstand | SMD | €0.01 | PANASONIC | ERJP06F1000V | Farnell | 1750741 | https://nl.farnell.com/panasonic/erjp06f1000v/res-100r-1-0-5w-0805-thick-film/dp/1750741?st=ERJP06%20Series
R2 | 1 | 120 Ω weerstand | SMD | €0.10 | PANASONIC | ERJP06F1200V | Farnell | 1750742 | https://be.farnell.com/panasonic/erjp06f1200v/res-120r-1-0-5w-0805-thick-film/dp/1750742
C3 | 1 | 27pF capacitor | SMD | €0.01 | WALSIN | 0805N270J500CT | Farnell | 2495527 | https://be.farnell.com/walsin/0805n270j500ct/cap-27pf-50v-5-c0g-np0-0805-reel/dp/2495527
U.FL | 1 | Male U.FL connector (antenna) | SMD | €0.97 | HIROSE(HRS) | U.FL-R-SMT(01) | Farnell | 3908021 | https://be.farnell.com/hirose-hrs/u-fl-r-smt-01/rf-coaxial-u-fl-straight-jack/dp/3908021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
C1 | 1 | 10µF capacitor | SMD | €0.88 | AVX | 0805ZC106KAT2A | Farnell | 2094042RL | https://be.farnell.com/avx/0805zc106kat2a/cap-mlcc-x7r-10uf-10v-0805/dp/2094042RL
C2 | 1 | 100nF capacitor | SMD | €0.32 | AVX | 08051C104K4T2A | Farnell | 1833888 | https://be.farnell.com/avx/08051c104k4t2a/cap-0-1-f-100v-10-x7r-0805/dp/1833888?st=100nf%20smd%200805
C4 | 1 | 1µF capacitor | SMD | €0.20 | AVX | 08053C105KAT2A | Farnell | 1658877 | https://be.farnell.com/avx/08053c105kat2a/cap-1-f-25v-10-x7r-0805/dp/1658877?st=1%C2%B5f%20smd%200805

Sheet: PCB HumidityTemp module
Referentie schema | # Stuks | Beschrijving component | Packaging | Prijs/stuk | Fabrikant | SKU Fabrikant | Leverancier | SKU Leverancier | URL Leverancier
C1 | 1 | 0.22µF capacitor | SMD | €0.29 | AVX | 08055C224KAT2A | Farnell | 1658878 | https://be.farnell.com/avx/08055c224kat2a/cap-0-22-f-50v-10-x7r-0805/dp/1658878?st=0.22%C2%B5F%20smd
C2 | 1 | 0.1µF capacitor | SMD | €0.32 | AVX | 08051C104K4T2A | Farnell | 1833888 | https://be.farnell.com/avx/08051c104k4t2a/cap-0-1-f-100v-10-x7r-0805/dp/1833888?st=100nf%20smd%200805
R | 2 | 2.2k resistors | SMD | €0.29 | PANASONIC | ERA6AEB222V | Farnell | 1577663 | https://be.farnell.com/panasonic/era6aeb222v/res-2k2-0-1-0-125w-0805-thin-film/dp/1577663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
HIH6030-021-001 | 1 | Humidity sensor | SMD | €7.89 | HONEYWELL | HIH6030-021-001 | Farnell | 2356755 | https://be.farnell.com/honeywell-s-c/hih-6030-021-001/sensor-humidity-no-filter-4-5-8soic/dp/2356755

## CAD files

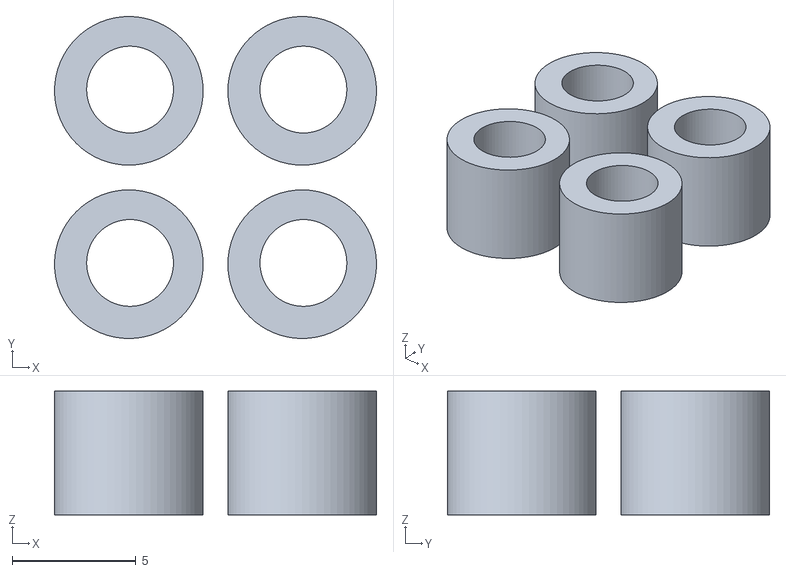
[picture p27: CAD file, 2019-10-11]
src/3D/m3_spacers_5mm.stl
13.0 x 13.0 x 5.00

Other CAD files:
src/pcb/lasercut/LaserCut_Jarno_MedicalDelivery2_v6.dxf
src/pcb/lasercut/LaserCut_Jarno_MedicalDelivery2_v5.dxf
src/pcb/lasercut/LaserCut_Jarno_MedicalDelivery2_v2.dxf
src/pcb/lasercut/LaserCut_Jarno_MedicalDelivery2_v4.dxf
src/pcb/lasercut/LaserCut_Jarno_MedicalDelivery2_v3.dxf

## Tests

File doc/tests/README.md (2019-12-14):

# Hardware Tests

Onder deze folder zijn alle gebeurde tests te vinden.

Via deze [template](testrapport.md) worden alle test geschreven vervolgens moeten alle stappen afgevinkt worden uit het [testplan](testplan.md).

## MCU tests
- [Test1](mcu/mcutest1.md) : Testing in progress

### SPI tests
- [Test1](mcu/spitest1.md) : NOK
- [Test2](mcu/spitest2.md) : OK

## LoRa tests
- [Test1 - XPlained Pro](lora/loratest1.md) : OK
- [Test2 - Integration MCU board and Lora Module](lora/loratest2.md) : NOK
- [Test3 - Integration MCU board and Lora Module](lora/loratest3.md) : OK

## Humidity tests
- [Test1](humidity/humiditytest1.md) : NOK
- [Test2](humidity/humiditytest2.md) : OK

## GPS tests
- [Test1](gps/gpstest1.md) : NOK

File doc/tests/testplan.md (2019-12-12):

# Testplan

## Testplan MCU

- [] Test wire connections 
    - [] VDD
        - [] Input supply between +2.5V & +12V
        - [] Humidity 3.3V
        - [] 9DoF 3.3V
        - [] GPS 3.3V
        - [] LoRa Module
    - [] GND
    - [] RX, TX
    - [] SDA, SCL
    - [] Reset
    - [] Switch
- [] Measure input supply voltages
- [] Measure voltages between VDD's and GND's
- [] Burn bootloader via [jp19-luwb burn bootloader doc](https://github.com/AP-Elektronica-ICT/jp19-luwb/blob/master/doc/AP%20Lokalisatie/Branden%20bootloader%20ATSAMD21G18/BootloaderBurningATSAMD21G18.md).
- [] Program blink led on MCU port PA12 [SWD Programming 2.1](../code/SWD_programming.md).
- [] Program LoRa library on MCU and send hardcoded string to LoRaWAN network.

## LoRa Module
- [] Test wire connections
    - [] Atnenna
    - [] DIO0
    - [] DI01
    - [] DI02
    - [] VDD
    - [] GND
    - [] Reset
- [] Connect LoRa module with MCU
    - [] Send string over LoRaWAN network.

## Testplan Sensor

- [] Test wire connections
    - [] VDD
    - [] GND
    - [] Specific sensor pins
- [] Log data on micrcontroller  
    - [] Every 2 secondes
    - [] Data should be printed as: NameSensor: xx.xx unit.
    - [] Add screenshot of timestamp and data

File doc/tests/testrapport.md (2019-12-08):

# Testrapport - Template
#### Datum: 00-00-0000
#### Code versie: code x.xx
#### Test done by: Tester
#### Tested with Microcontroller: MicroController name
 
## Test sensor X (Do this for each sensor/MCU - Component you are testing)

Testplan checklist

## Besluit
Schrijf hier je besluit van de testen

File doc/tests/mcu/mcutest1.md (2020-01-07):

# Testrapport - MCU Board
#### Datum: 8-12-2019
#### Code versie: Nvt.
#### Test done by: Oussama Es-Salhi
 
## Test MCU 1

- [NOK] Test wire connections 
    - [OK] VDD
        - [OK] Input supply between +2.5V & +12V
        - [OK] Humidity 3.3V
        - [OK] 9DoF 3.3V
        - [OK] GPS 3.3V
        - [OK] LoRa Module
    - [OK] GND
    - [OK] RX, TX
    - [OK] SDA, SCL
    - [OK] Reset
    - [NOK] Reset switch
- [OK] Measure input supply voltages
- [OK] Measure voltages between VDD's and GND's
- [OK] Burn bootloader via [jp19-luwb burn bootloader doc](https://github.com/AP-Elektronica-ICT/jp19-luwb/blob/master/doc/AP%20Lokalisatie/Branden%20bootloader%20ATSAMD21G18/BootloaderBurningATSAMD21G18.md).
- [OK] Program blink led on MCU port PA12 [SWD Programming 2.1](../code/SWD_programming.md).
- [NOK] Reset switch
- [OK] Program LoRa library on MCU and send hardcoded string to LoRaWAN network.

*Swtich changes voltage to 0V to reset*

## Test MCU 2

- [OK] Test wire connections 
    - [OK] VDD
        - [OK] Input supply between +2.5V & +12V
        - [OK] Humidity 3.3V
        - [OK] 9DoF 3.3V
        - [OK] GPS 3.3V
        - [OK] LoRa Module
    - [OK] GND
    - [OK] RX, TX
    - [OK] SDA, SCL
    - [OK] Reset
    - [OK] Switch
- [OK] Measure input supply voltages
- [OK] Measure voltages between VDD's and GND's
- [OK] Burn bootloader via [jp19-luwb burn bootloader doc](https://github.com/AP-Elektronica-ICT/jp19-luwb/blob/master/doc/AP%20Lokalisatie/Branden%20bootloader%20ATSAMD21G18/BootloaderBurningATSAMD21G18.md).
- [OK] Program blink led on MCU port PA12 [SWD Programming 2.1](../code/SWD_programming.md).
- [NOK] Reset switch
- [OK] Program LoRa library on MCU and send hardcoded string to LoRaWAN network.

## Test MCU 4

- [OK] Test wire connections 
    - [OK] VDD
        - [OK] Input supply between +2.5V & +12V
        - [OK] Humidity 3.3V
        - [OK] 9DoF 3.3V
        - [OK] GPS 3.3V
        - [OK] LoRa Module
    - [OK] GND
    - [OK] RX, TX
    - [OK] SDA, SCL
    - [OK] Reset
    - [OK] Switch
- [OK] Measure input supply voltages
- [OK] Measure voltages between VDD's and GND's
- [OK] Burn bootloader via [jp19-luwb burn bootloader doc](https://github.com/AP-Elektronica-ICT/jp19-luwb/blob/master/doc/AP%20Lokalisatie/Branden%20bootloader%20ATSAMD21G18/BootloaderBurningATSAMD21G18.md).
- [OK] Program blink led on MCU port PA12 [SWD Programming 2.1](../code/SWD_programming.md).
- [NOK] Reset switch
- [OK] Program LoRa library on MCU and send hardcoded string to LoRaWAN network.

## Besluit
Switch does what it is designed for but doesn't reset the program. Alternative reset => Reset pins on mcu connect them with each other and disconnect from each other => program resets.

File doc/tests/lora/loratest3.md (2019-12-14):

# Testrapport - LoRa Module
#### Datum: 12-12-2019
#### Code versie: code 1.00
#### Test done by: Oussama Es-Salhi & Jarno Cools
#### Tested with Microcontroller: [MCU Module - 1.LoRa module pins](../../electrical_scheme.md)
 
## Test LoRa 1

- [OK] Test wire connections
    - [OK] Atnenna
    - [OK] DIO0
    - [OK] DI01
    - [OK] DI02
    - [OK] VDD
    - [OK] GND
    - [OK] Reset
    - [1*] MISO : Same for every LoRa Module
    - [1*] MOSI : Same for every LoRa Module
    - [1*] SCK : Same for every LoRa Module
    - [OK] NSS
- [OK] Connect LoRa module with MCU
    - [OK] Send string over LoRaWAN network.

## Test LoRa 2

- [OK] Test wire connections
    - [OK] Atnenna
    - [OK] DIO0
    - [OK] DI01
    - [OK] DI02
    - [OK] VDD
    - [OK] GND
    - [OK] Reset
    - [1*] MISO : Same for every LoRa Module
    - [1*] MOSI : Same for every LoRa Module
    - [1*] SCK : Same for every LoRa Module
    - [OK] NSS
- [OK] Connect LoRa module with MCU
    - [OK] Send string over LoRaWAN network.

## Besluit

Tests gebeurd via SPI legacy verholpen probleem niet. Wanneer serial.print blijft hangen in een print statement betekent dit dat er een slechte connectie is tussen de lora module en de microcontroller. SPI veranderd in LoRa library naar SPI waar de LoRa is op aangesloten SERCOM 1.

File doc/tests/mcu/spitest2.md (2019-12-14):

# Testrapport - SPI MCU Module - Arduino Nano
#### Datum: 13-12-2019
#### Code versie: Nvt
#### Test done by: Oussama Es-Salhi & Jarno Cools
#### Tested with Microcontroller: MCU Module
 
## LoRa Module 1
- [OK] Simple SPI sercom with Arduino Nano [SPI tutorial link](https://circuits4you.com/2019/01/03/arduino-spi-communication-example/) 
- [OK] Library LMIC 
- [OK] TinyLoRa -> In library sercom toegevoegd zodat ipv de basic SPI de SPI de SPI sercom zou gebruiken

## Besluit
Bedrading aanpassen van LoRa modules zodat we de juiste sercoms kunnen gebruiken. SERCOM1 gebruiken   
- MOSI: PA16 - 11 - sercom1 [0]    
- SCK: PA17 - 13 - sercom1 [1]    
- MISO: PA18 - 10 - sercom1 [2]

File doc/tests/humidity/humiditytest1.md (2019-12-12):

# Testrapport - Humidity Sensor HIH6030 SMD 8 pins

#### Datum: 06-12-2019
#### Code versie: Eerste code met gewoon Wire library
#### Test done by: Cristian Baba
#### Tested with Microcontroller: Arduino NANO

## Test sensor 1

- [OK] Test wire connections
    - [OK] VDD
    - [OK] GND
    - [OK] Specific sensor pins
- [NOK] Log data on micrcontroller  
    - [OK] Every 2 secondes
    - [NOK] Data should be printed as: NameSensor: xx.xx unit.
    - [OK] Add screenshot of timestamp and data

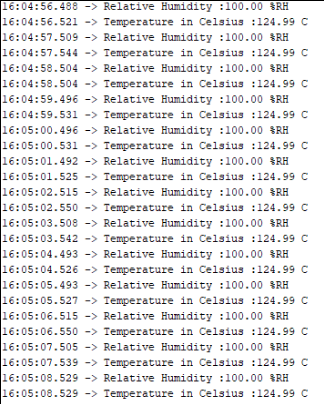
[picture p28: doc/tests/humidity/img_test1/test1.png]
Serial print test1


Bevindingen: Incorrecte data humidity is 100%.

## Test sensor 2

- [OK] Test wire connections
    - [OK] VDD
    - [OK] GND
    - [OK] Specific sensor pins
- [OK] Log data on micrcontroller  
    - [OK] Every 2 secondes
    - [OK] Data should be printed as: NameSensor: xx.xx unit.
    - [OK] Add screenshot of timestamp and data

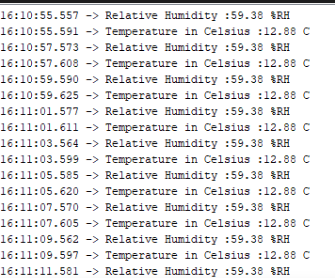
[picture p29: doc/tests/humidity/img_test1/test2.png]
Serial print test2


Bevindingen: Te koude temperatuur, humidity zou kunnen kloppen.

## Test sensor 3

- [OK] Test wire connections
    - [OK] VDD
    - [OK] GND
    - [OK] Specific sensor pins
- [OK] Log data on micrcontroller  
    - [OK] Every 2 secondes
    - [OK] Data should be printed as: NameSensor: xx.xx unit.
    - [OK] Add screenshot of timestamp and data

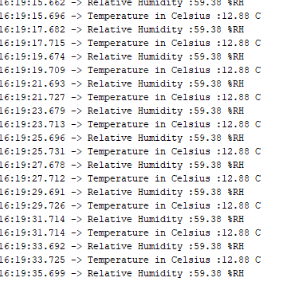
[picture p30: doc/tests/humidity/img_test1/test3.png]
Serial print test3


## Test sensor 4

- [OK] Test wire connections
    - [OK] VDD
    - [OK] GND
    - [OK] Specific sensor pins
- [OK] Log data on micrcontroller  
    - [OK] Every 2 secondes
    - [OK] Data should be printed as: NameSensor: xx.xx unit.
    - [OK] Add screenshot of timestamp and data

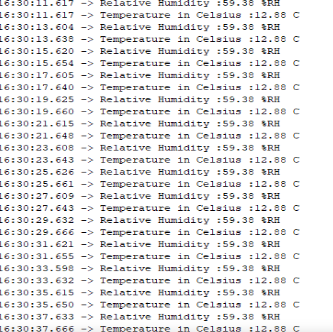
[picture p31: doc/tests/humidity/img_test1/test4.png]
Serial print test4


## Test sensor 5

- [OK] Test wire connections
    - [OK] VDD
    - [OK] GND
    - [OK] Specific sensor pins
- [OK] Log data on micrcontroller  
    - [OK] Every 2 secondes
    - [OK] Data should be printed as: NameSensor: xx.xx unit.
    - [OK] Add screenshot of timestamp and data

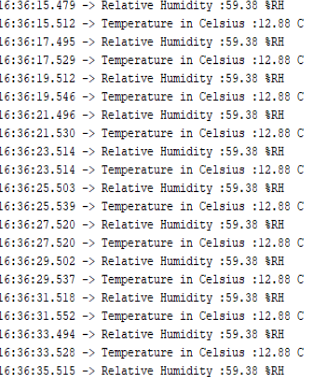
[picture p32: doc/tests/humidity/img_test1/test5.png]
Serial print test5


## Besluit
Alle aansluitingen lijken te testen, 1ste sensor gaf een humidity van 100%. Deze lijkt een misfunction te hebben, op de achterkant aangeduid met een blauwe 1. Nieuwe code schrijven en alle sensoren opnieuw testen.

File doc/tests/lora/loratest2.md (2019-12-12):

# Testrapport - LoRa Module
#### Datum: 12-12-2019
#### Code versie: code 1.00
#### Test done by: Oussama Es-Salhi & Jarno Cools
#### Tested with Microcontroller: [MCU Module - 1.LoRa module pins](../../electrical_scheme.md)
 
## Test LoRa 1

- [OK] Test wire connections
    - [OK] Atnenna
    - [OK] DIO0
    - [OK] DI01
    - [OK] DI02
    - [OK] VDD
    - [OK] GND
    - [OK] Reset
    - [1*] MISO : Same for every LoRa Module
    - [1*] MOSI : Same for every LoRa Module
    - [1*] SCK : Same for every LoRa Module
    - [OK] NSS
- [NOK] Connect LoRa module with MCU
    - [NOK] Send string over LoRaWAN network.

## Test LoRa 2

- [OK] Test wire connections
    - [OK] Atnenna
    - [OK] DIO0
    - [OK] DI01
    - [OK] DI02
    - [OK] VDD
    - [OK] GND
    - [OK] Reset
    - [1*] MISO : Same for every LoRa Module
    - [1*] MOSI : Same for every LoRa Module
    - [1*] SCK : Same for every LoRa Module
    - [OK] NSS
- [NOK] Connect LoRa module with MCU
    - [NOK] Send string over LoRaWAN network.

## Besluit

SPI van LoRa libraries werkt niet, library aangepast zodat SPI van SERCOM3 gebruik wordt. Uitslag: Geen verschil gemaakt. Fout ligt niet bij LoRa modules maar bij de library. Mogelijkheid dat wanneer legacy ISCP gebruikt werd van de SAMD21 dat het we zou werken.

1*: The SAMD21 has specific pins for the SPI connection we used the right SPI pins on our MCU module but connected them with the wrong connected pin.   
MISO was connected with PA16 and should be connected with PA18  
MOSI was connected with PA17 and should be connected with PA16  
SCK was connected with PA18 and should be connected with PA17  

*This could be fixed by cutting the three lines and solder them with some cable to the right LoRa pin connection => then our LoRa module would still be able to be plugged in into our MCU board.*

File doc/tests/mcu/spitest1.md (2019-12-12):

# Testrapport - SPI MCU Module - Arduino Nano
#### Datum: 12-12-2019
#### Code versie: Nvt
#### Test done by: Oussama Es-Salhi & Jarno Cools
#### Tested with Microcontroller: MCU Module
 
- [OK] Simple SPI sercom with Arduino Nano [SPI tutorial link](https://circuits4you.com/2019/01/03/arduino-spi-communication-example/) 
- [NOK] Library LMIC 
- [NOK] TinyLoRa -> In library sercom toegevoegd zodat ipv de basic SPI de SPI de SPI sercom zou gebruiken

## Besluit
Alles met verschillende LoRa modules getest.

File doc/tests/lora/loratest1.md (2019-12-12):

# Testrapport - LoRa Module
#### Datum: 30-10-2019
#### Code versie: code 1.00
#### Test done by: Oussama Es-Salhi & Jarno Cools
#### Tested with Microcontroller: SAM D21 Xplained Pro
#### Pinout used [SAM D21 Xplained Pro](../../img/Xplained_Pro_pinout.png)
 
## Test LoRa 1 - PCB 1 (PCB met cnc machine op school gemaakt)

- [OK] Test wire connections
    - [OK] Atnenna
    - [OK] DIO0
    - [OK] DI01
    - [OK] DI02
    - [OK] VDD
    - [OK] GND
    - [OK] Reset
    - [OK] MISO
    - [OK] MOSI
    - [OK] SCK
    - [OK] NSS
- [OK] Connect LoRa module with MCU
    - [OK] Send string over LoRaWAN network.

## Test LoRa 2 - PCB 2 (PCB van onze bestelling bij JLCPCB)
- [OK] Test wire connections
    - [OK] Atnenna
    - [OK] DIO0
    - [OK] DI01
    - [OK] DI02
    - [OK] VDD
    - [OK] GND
    - [OK] Reset
    - [OK] MISO
    - [OK] MOSI
    - [OK] SCK
    - [OK] NSS
- [OK] Connect LoRa module with MCU
    - [OK] Send string over LoRaWAN network.

## Besluit
Geen problemen ondervonden bij het testen van onze LoRa modules samen met de SAM D21 Xplained Pro.
Getest samen met GPS module. Verbinding via jumper wires gebeurd.

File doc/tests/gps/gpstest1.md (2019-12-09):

# Testrapport - GPS Sensor
#### Datum: 22-10-2019
#### Code versie: Nvt.
#### Test done by: Jarno Cools
 
## Test sensor 1

- [NOK] Test wire connections
    - [NOK] VDD
    - [OK] GND
    - [NOK] Specific sensor pins
- [] Log data on micrcontroller  
    - [] Every 2 secondes
    - [] Data should be printed as: NameSensor: xx.xx unit.
    - [] Add screenshot of timestamp and data

## Test sensor 2

- [NOK] Test wire connections
    - [OK] VDD
    - [OK] GND
    - [NOK] Specific sensor pins
- [] Log data on micrcontroller  
    - [] Every 2 secondes
    - [] Data should be printed as: NameSensor: xx.xx unit.
    - [] Add screenshot of timestamp and data

## Test sensor 3

- [NOK] Test wire connections
    - [NOK] VDD
    - [OK] GND
    - [NOK] Specific sensor pins
        - [OK] Antenna
        - [NOK] RX
- [] Log data on micrcontroller  
    - [] Every 2 secondes
    - [] Data should be printed as: NameSensor: xx.xx unit.
    - [] Add screenshot of timestamp and data

## Besluit
Package van interent genomen te klein, overstappen op GY-NEO6MV2 gps module.

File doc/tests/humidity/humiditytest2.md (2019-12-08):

# Testrapport - Humidity Sensor HIH6030 SMD 8 pins

#### Datum: 07-12-2019
#### Code versie: Library van HIH61xx geimport en getest met de example sketch
#### Test done by: Oussama Es-Salhi
#### Tested with Microcontroller: Arduino NANO

## Test sensor 1

- [OK] Test wire connections
    - [OK] VDD
    - [OK] GND
    - [OK] Specific sensor pins
- [OK] Log data on micrcontroller  
    - [OK] Every 2 secondes
    - [OK] Data should be printed as: NameSensor: xx.xx unit.
    - [OK] Add screenshot of timestamp and data

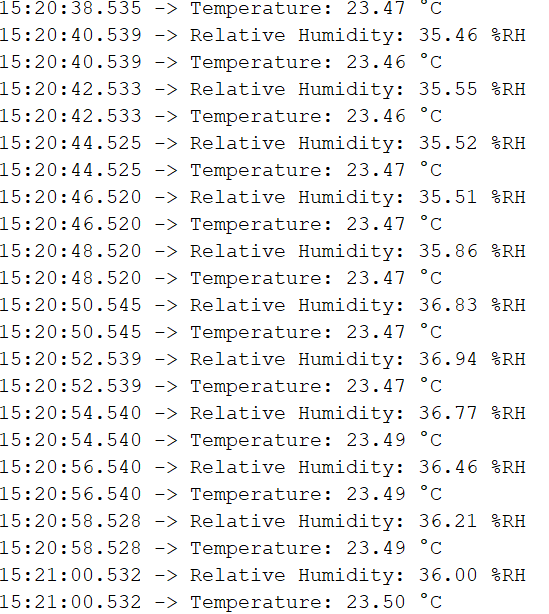
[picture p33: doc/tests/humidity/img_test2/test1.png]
Serial print test1


## Test sensor 2

- [OK] Test wire connections
    - [OK] VDD
    - [OK] GND
    - [OK] Specific sensor pins
- [OK] Log data on micrcontroller  
    - [OK] Every 2 secondes
    - [OK] Data should be printed as: NameSensor: xx.xx unit.
    - [OK] Add screenshot of timestamp and data

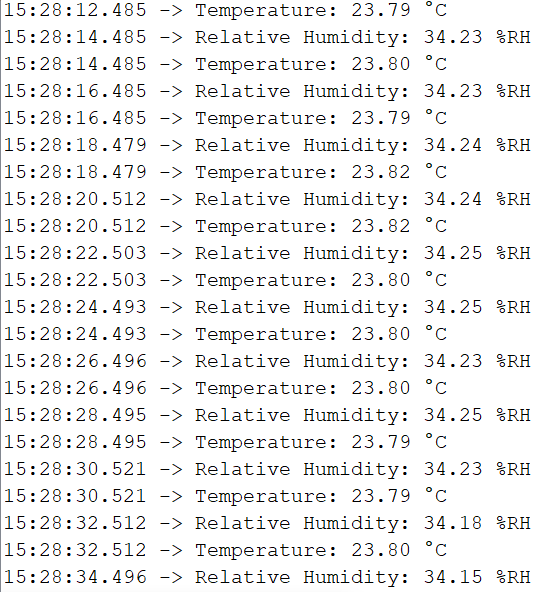
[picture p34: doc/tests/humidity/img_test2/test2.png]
Serial print test2


## Test sensor 3

- [OK] Test wire connections
    - [OK] VDD
    - [OK] GND
    - [OK] Specific sensor pins
- [OK] Log data on micrcontroller  
    - [OK] Every 2 secondes
    - [OK] Data should be printed as: NameSensor: xx.xx unit.
    - [OK] Add screenshot of timestamp and data

Serial print test3

## Test sensor 4

- [OK] Test wire connections
    - [OK] VDD
    - [OK] GND
    - [OK] Specific sensor pins
- [OK] Log data on micrcontroller  
    - [OK] Every 2 secondes
    - [OK] Data should be printed as: NameSensor: xx.xx unit.
    - [OK] Add screenshot of timestamp and data

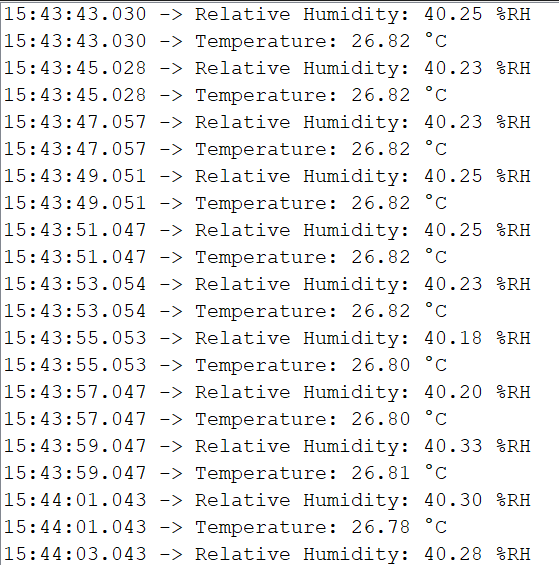
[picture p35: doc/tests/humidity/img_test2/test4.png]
Serial print test4


## Test sensor 5

- [OK] Test wire connections
    - [OK] VDD
    - [OK] GND
    - [OK] Specific sensor pins
- [OK] Log data on micrcontroller  
    - [OK] Every 2 secondes
    - [OK] Data should be printed as: NameSensor: xx.xx unit.
    - [OK] Add screenshot of timestamp and data

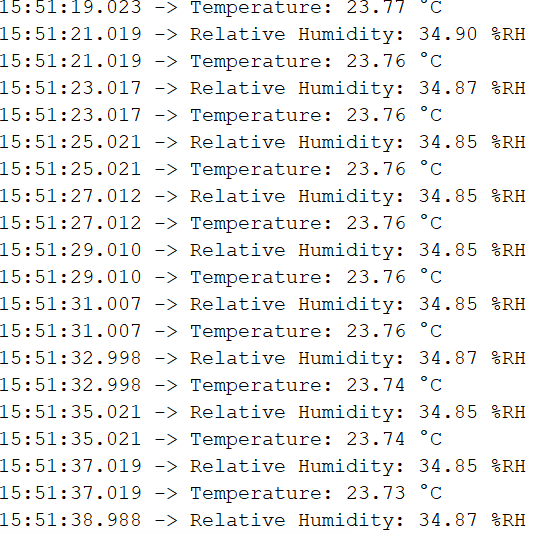
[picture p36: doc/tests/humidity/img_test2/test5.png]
Serial print test5


## Besluit
Na de nieuwe code erop te hebben gezet krijgen we waarden die juist zouden kunnen zijn, nog nakijken met ander meetinstrument bv. temperatuur sensor om te kijken of de sensoren kloppen.
Sensor 2 heeft een temperatuur die 2 graden celcius hoger ligt dan de anderen.

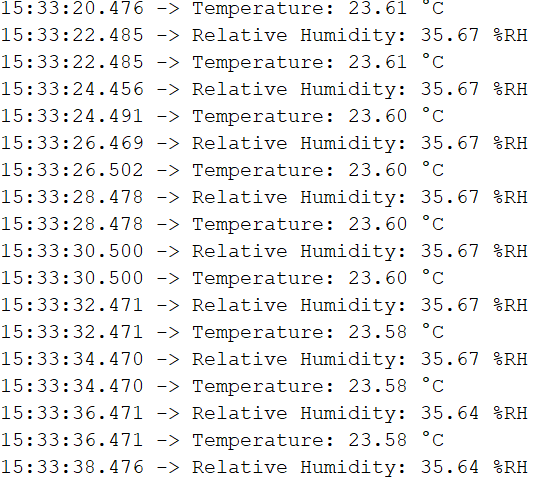
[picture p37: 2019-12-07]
doc/tests/humidity/img_test2/test3.png

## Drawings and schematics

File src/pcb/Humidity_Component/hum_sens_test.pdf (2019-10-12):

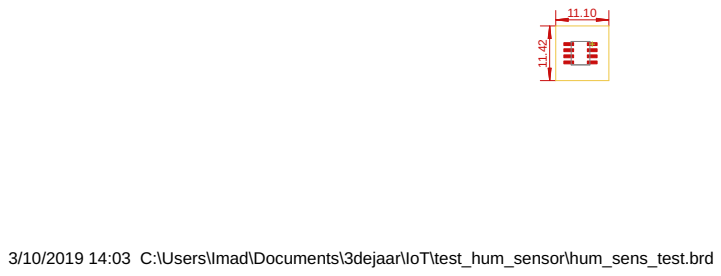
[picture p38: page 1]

3/10/2019 14:03 C:\Users\Imad\Documents\3dejaar\IoT\test_hum_sensor\hum_sens_test.brd

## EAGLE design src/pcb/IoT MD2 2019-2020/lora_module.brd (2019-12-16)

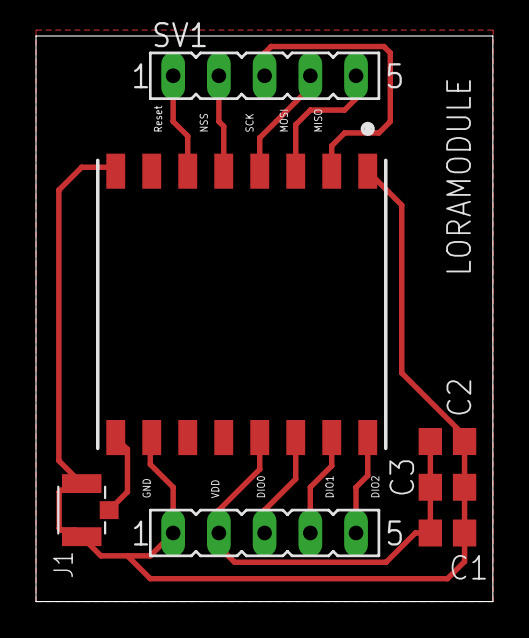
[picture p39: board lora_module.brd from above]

Board: 2 copper layers, 25.4 x 31.4 mm, 7 parts (0 on the bottom side), 11 nets.

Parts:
C1: 1uF; C0805
C2: 10uF; C0805
C3: 100nF; C0805
J1: U.FL-R-SMT-1(10); HRS_U.FL-R-SMT-1(10)
LORAMODULE: RFM95W-868S2; XCVR_RFM95W-868S2
SV1, SV2: FE05-1

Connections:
DIO0: LORAMODULE.14, SV2.3
DIO1: LORAMODULE.15, SV2.4
DIO2: LORAMODULE.16, SV2.5
GND: C1.2, C2.2, C3.2, J1.1, J1.3, LORAMODULE.1, LORAMODULE.8, LORAMODULE.10, SV2.1
MISO: LORAMODULE.2, SV1.3
MOSI: LORAMODULE.3, SV1.5
unnamed: J1.2, LORAMODULE.9
NSS: LORAMODULE.5, SV1.2
RESET_LORA: LORAMODULE.6, SV1.1
SCK: LORAMODULE.4, SV1.4
VDD: C1.1, C2.1, C3.1, LORAMODULE.13, SV2.2

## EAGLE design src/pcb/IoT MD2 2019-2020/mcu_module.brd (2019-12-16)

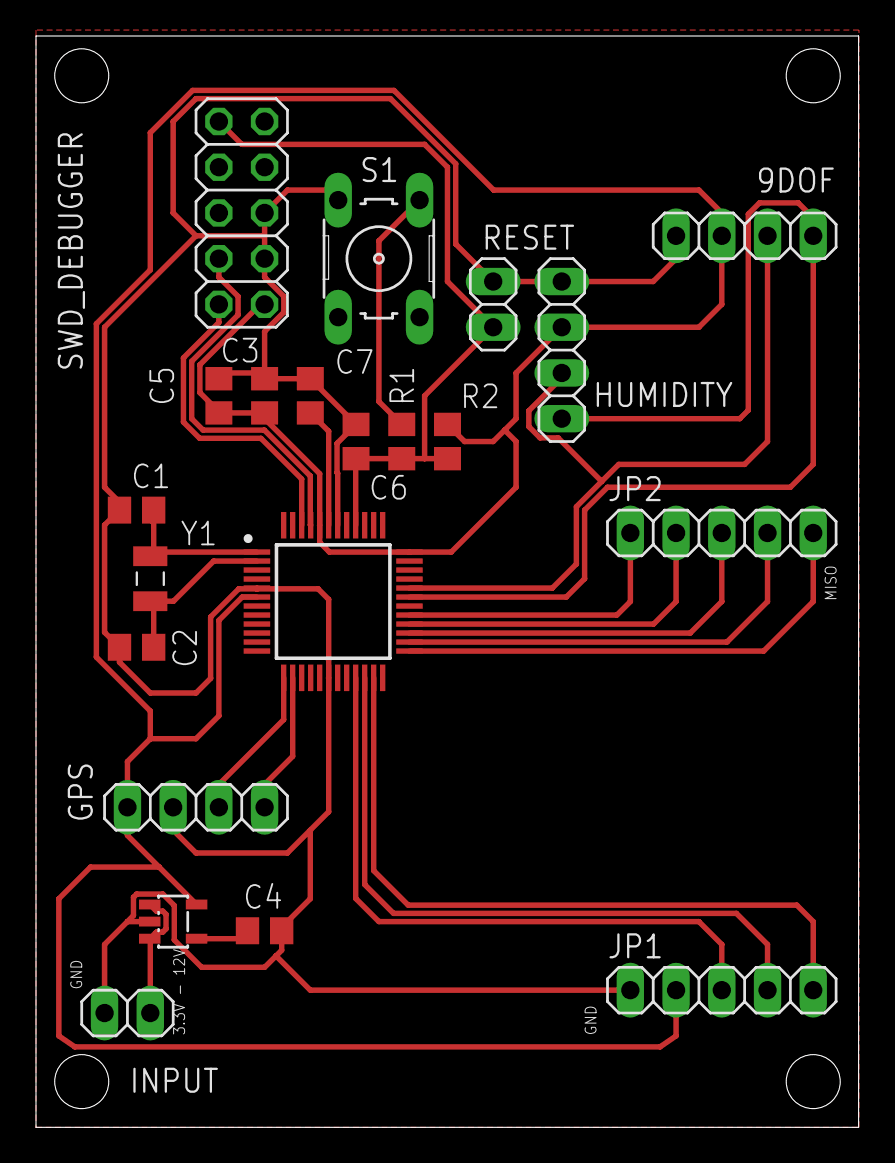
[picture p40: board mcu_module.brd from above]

Board: 2 copper layers, 45.7 x 60.6 mm, 21 parts (0 on the bottom side), 23 nets.

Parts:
9DOF: 1X04
C1, C2: 15pF; C0805
C3: 2.2uF; C0805
C4: 470pF; C0805
C5: 0.1uF; C0805
C6: 100nF; C0805
C7: 1uF; C0805
GPS: 1X04
HUMIDITY: 1X04
IC1: SOT23-5
IC2: ATSAMD21G18A-AU; QFP50P900X900X120-48N
INPUT: 1X02
JP1, JP2: 1X05
R1: 10k; R0805
R2: 330; R0805
RESET: 1X02
S1: B3F-10XX
SWD_DEBUGGER: 2X05
Y1: ABS07-32.768KHZ-T; XTAL_ABS07-32.768KHZ-T

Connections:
BYP: C4.1, IC1.4
DIO0: IC2.21, JP1.3
DIO1: IC2.22, JP1.4
DIO2: IC2.23, JP1.5
GND: 9DOF.1, C1.2, C2.2, C3.2, C4.2, C5.2, C6.2, C7.2, GPS.3, HUMIDITY.1, IC1.2, IC2.5, IC2.18, IC2.42, INPUT.2, JP1.1, RESET.2, S1.3, SWD_DEBUGGER.3, SWD_DEBUGGER.5
INPUT: IC1.1, IC1.3, INPUT.1
MISO: IC2.25, JP2.5
MOSI: IC2.26, JP2.4
unnamed: C1.1, IC2.1, Y1.1
unnamed: C2.1, IC2.2, Y1.2
unnamed: R2.1, S1.1
NSS: IC2.28, JP2.2
RESET: C6.1, IC2.40, R1.1, R2.2, RESET.1, SWD_DEBUGGER.10
RESET_LORA: IC2.29, JP2.1
RX: GPS.2, IC2.13
SCK: IC2.27, JP2.3
SCL: 9DOF.4, HUMIDITY.4, IC2.31
SDA: 9DOF.3, HUMIDITY.3, IC2.32
SWDCLK: IC2.45, SWD_DEBUGGER.4
SWDIO: IC2.46, SWD_DEBUGGER.2
TX: GPS.1, IC2.14
VDD: 9DOF.2, C3.1, C5.1, GPS.4, HUMIDITY.2, IC1.5, IC2.6, IC2.36, IC2.44, JP1.2, R1.2, SWD_DEBUGGER.1
VDDCORE: C7.1, IC2.43

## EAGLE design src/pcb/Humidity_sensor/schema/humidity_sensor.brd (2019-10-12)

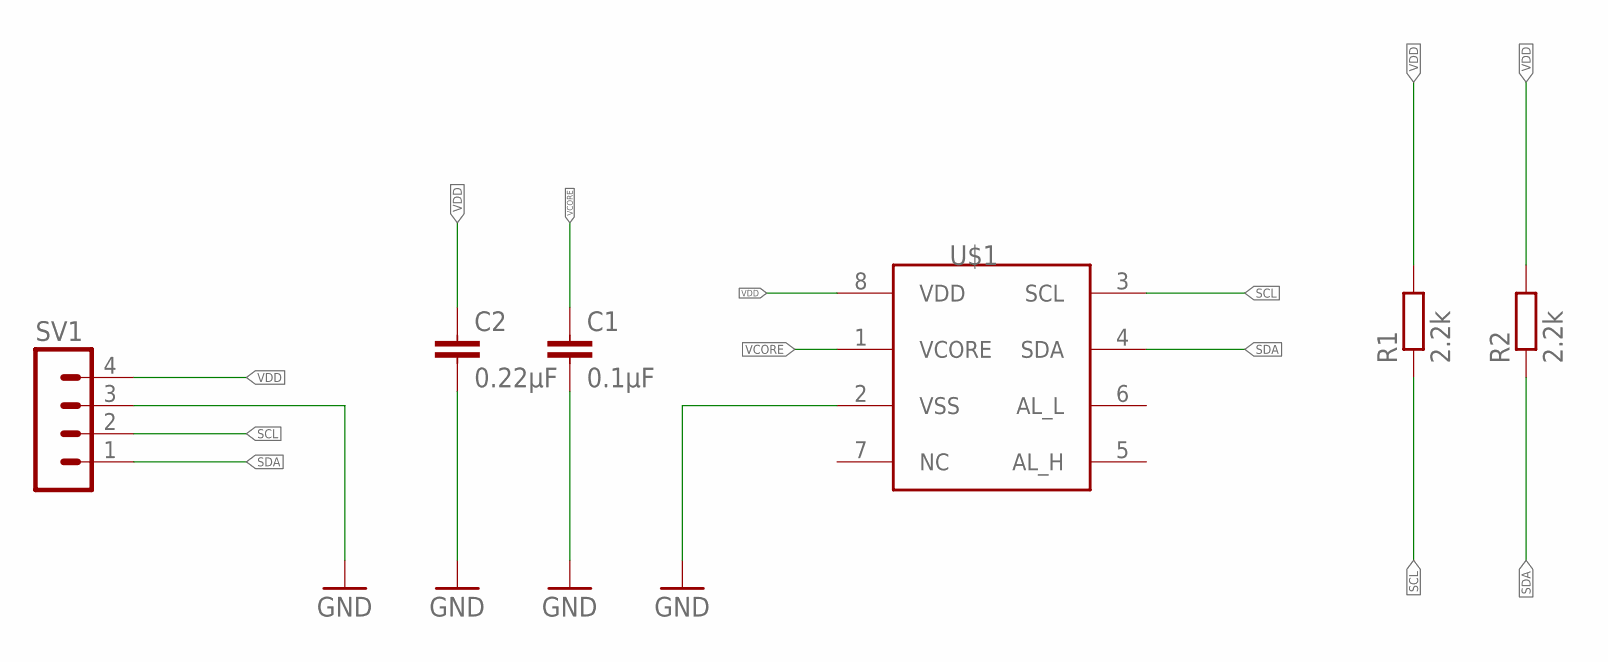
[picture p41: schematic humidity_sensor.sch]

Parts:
C1: 0.1µF; C0805
C2: 0.22µF; C0805
R1, R2: 2.2k; R0805
SV1: MA04-1
U$1: HIH6030-021-001SMD; HIH6030-021-001

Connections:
GND: C1.2, C2.2, SV1.3, U$1.2 (VSS)
SCL: R1.1, SV1.2, U$1.3 (SCL)
SDA: R2.1, SV1.1, U$1.4 (SDA)
VCORE: C1.1, U$1.1 (VCORE)
VDD: C2.1, R1.2, R2.2, SV1.4, U$1.8 (VDD)

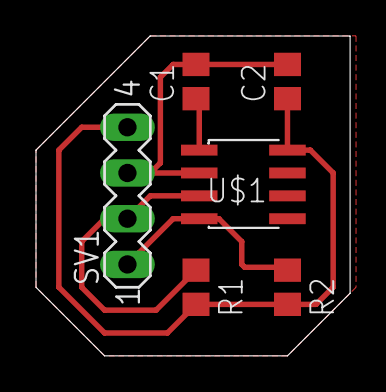
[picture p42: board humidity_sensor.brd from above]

Board: 2 copper layers, 17.4 x 17.8 mm, 6 parts (0 on the bottom side), 5 nets.

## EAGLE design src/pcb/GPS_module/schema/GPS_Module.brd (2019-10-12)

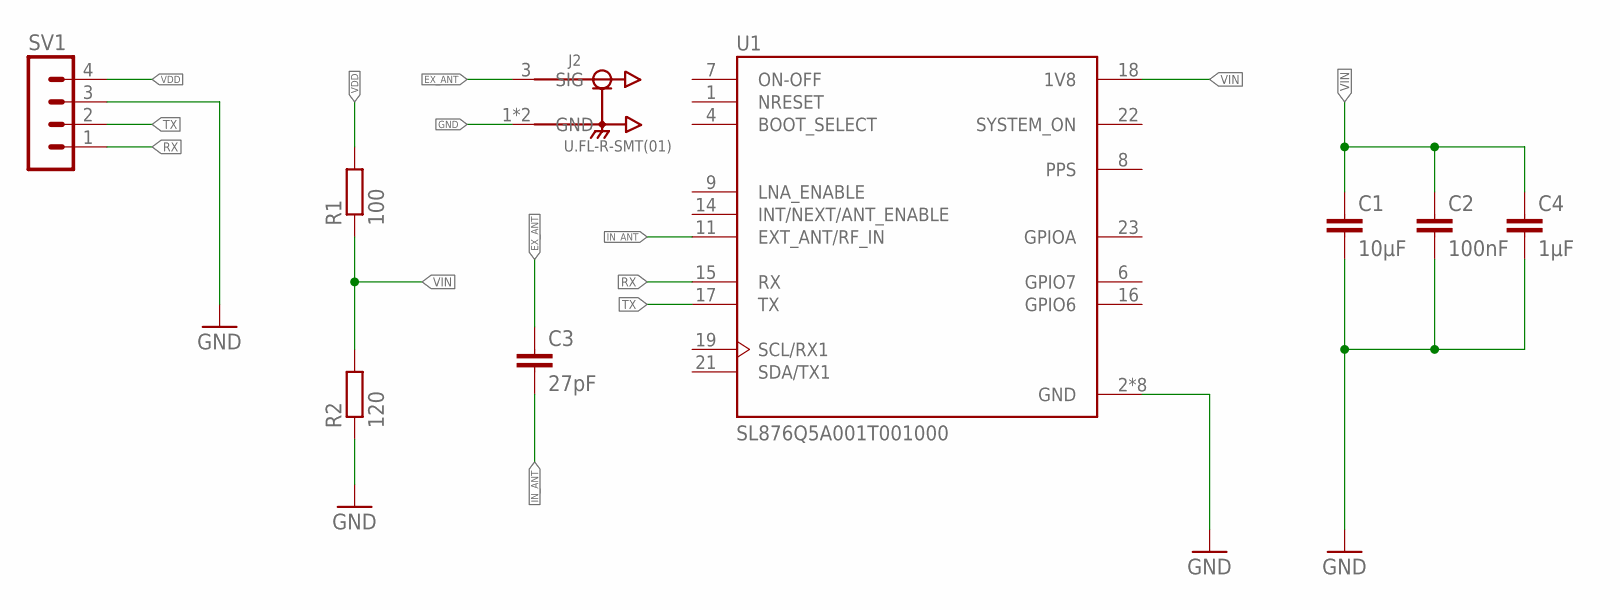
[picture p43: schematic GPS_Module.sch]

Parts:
C1: 10µF; C0805
C2: 100nF; C0805
C3: 27pF; C0805
C4: 1µF; C0805
J2: U.FL-R-SMT(01); HRS_U.FL-R-SMT(01)
R1: 100; R0805
R2: 120; R0805
SV1: MA04-1
U1: SL876Q5A001T001000; XCVR_SL876Q5A001T001000

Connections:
EX_ANT: C3.1, J2.3 (SIG)
GND: C1.2, C2.2, C4.2, J2.1 (GND), J2.2 (GND), R2.1, SV1.3, U1.2 (GND), U1.3 (GND), U1.5 (GND), U1.10 (GND), U1.12 (GND), U1.13 (GND), U1.20 (GND), U1.24 (GND)
IN_ANT: C3.2, U1.11 (EXT_ANT/RF_IN)
RX: SV1.1, U1.15 (RX)
TX: SV1.2, U1.17 (TX)
VDD: R1.2, SV1.4
VIN: C1.1, C2.1, C4.1, R1.1, R2.2, U1.18 (1V8)

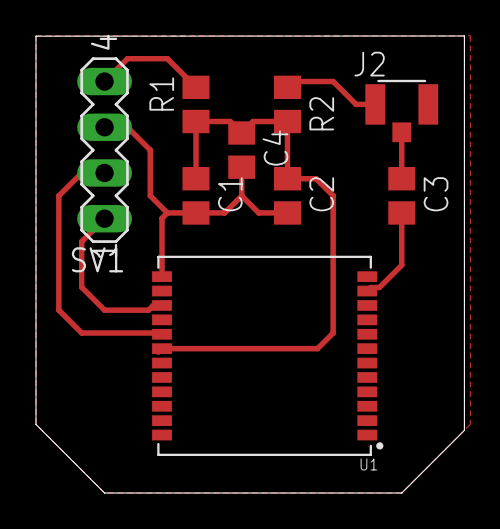
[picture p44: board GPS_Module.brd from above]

Board: 2 copper layers, 23.8 x 25.4 mm, 9 parts (0 on the bottom side), 7 nets.

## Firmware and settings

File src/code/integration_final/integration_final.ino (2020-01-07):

#include <lmic.h>
#include <hal/hal.h>
#include <SPI.h>
#include "wiring_private.h"
#include <TinyGPS++.h>
#include <LoraEncoder.h>
#include <Wire.h>
#include <HIH61xx.h>
#include <AsyncDelay.h>
#include <SparkFunLSM9DS1.h>
#define LSM9DS1_M 0x1E
#define LSM9DS1_AG 0x6B
#define DECLINATION -8.58 // Declination (degrees) in Boulder, CO.

Uart GPSSerial(&sercom2, 3, 4, SERCOM_RX_PAD_1, UART_TX_PAD_0); // create uart on pin 3 and 4 for GPS
void SERCOM2_Handler()
{
  GPSSerial.IrqHandler();
}
int GPSBaud = 9600;
int16_t Temperature;
uint16_t relativeHumidity;
float Lat, Long, GForce;
bool IsHumidityOutOfBoundary, IsTemperatureOutOfBoundary, IsTiltedOutOfBoundary, ShockDetected;
float tiltedBoundaryDegrees = 45;
float TemperatureBoundary[] = {-20, 40}; //{LOW, HIGH}
float HumidityBoundary[] = {0, 55};      //{LOW, HIGH}
TinyGPSPlus gps;
AsyncDelay samplingInterval;
HIH61xx<TwoWire> hih(Wire);
byte payload[12];
LoraEncoder encoder(payload);
LSM9DS1 imu;
static const PROGMEM u1_t NWKSKEY[16] = {0x96, 0x74, 0x6C, 0x57, 0xD8, 0xE3, 0xB1, 0xD6, 0x3A, 0x04, 0x83, 0x04, 0xC4, 0x56, 0x8D, 0x36};
static const u1_t PROGMEM APPSKEY[16] = {0x1F, 0x42, 0x97, 0x73, 0xAE, 0xEA, 0xDA, 0xE8, 0xD4, 0xEE, 0x45, 0xF7, 0x54, 0xD4, 0xAE, 0x57};
static const u4_t DEVADDR = 0x26011BFE;
void os_getArtEui(u1_t *buf) {}
void os_getDevEui(u1_t *buf) {}
void os_getDevKey(u1_t *buf) {}

static osjob_t sendjob;
const unsigned TX_INTERVAL = 30;

const lmic_pinmap lmic_pins = {
    .nss = 12,
    .rxtx = LMIC_UNUSED_PIN,
    .rst = 6,
    .dio = {38, 2, LMIC_UNUSED_PIN},
};

void onEvent(ev_t ev)
{
  Serial.print(os_getTime());
  Serial.print(": ");
  switch (ev)
  {
  case EV_TXCOMPLETE:
    Serial.println(F("EV_TXCOMPLETE (includes waiting for RX windows)"));
    if (LMIC.txrxFlags & TXRX_ACK)
      Serial.println(F("Received ack"));
    if (LMIC.dataLen)
    {
      Serial.println(F("Received "));
      Serial.println(LMIC.dataLen);
      Serial.println(F(" bytes of payload"));
    }
    // Schedule next transmission
    os_setTimedCallback(&sendjob, os_getTime() + sec2osticks(TX_INTERVAL), do_send);
    break;
  default:
    Serial.println(F("Unknown event"));
    break;
  }
}

void do_send(osjob_t *j)
{
  if (LMIC.opmode & OP_TXRXPEND)
    Serial.println(F("OP_TXRXPEND, not sending"));
  else
  {
    encoder.writeTemperature(Temperature);
    encoder.writeHumidity(relativeHumidity);
    encoder.writeLatLng(Lat, Long);
    encoder.writeBitmap(IsTemperatureOutOfBoundary, IsHumidityOutOfBoundary,
                        IsTiltedOutOfBoundary, ShockDetected, false, false, false, false);
    LMIC_setTxData2(1, payload, sizeof(payload) - 1, 0);
    Serial.println(F("Packet queued"));
  }
}

void setup()
{
  Serial.begin(115200);
  Serial.println("Starting");
  GPSSerial.begin(GPSBaud);
  pinPeripheral(3, PIO_SERCOM_ALT);
  pinPeripheral(4, PIO_SERCOM_ALT);
  samplingInterval.start(2000, AsyncDelay::MILLIS);
  Wire.begin();
  hih.initialise();
  delay(100);
  os_init();
  LMIC_reset();
#ifdef PROGMEM
  uint8_t appskey[sizeof(APPSKEY)];
  uint8_t nwkskey[sizeof(NWKSKEY)];
  memcpy_P(appskey, APPSKEY, sizeof(APPSKEY));
  memcpy_P(nwkskey, NWKSKEY, sizeof(NWKSKEY));
  LMIC_setSession(0x1, DEVADDR, nwkskey, appskey);
#endif
  LMIC_setupChannel(0, 868100000, DR_RANGE_MAP(DR_SF12, DR_SF7), BAND_CENTI);  // g-band
  LMIC_setupChannel(1, 868300000, DR_RANGE_MAP(DR_SF12, DR_SF7B), BAND_CENTI); // g-band
  LMIC_setupChannel(2, 868500000, DR_RANGE_MAP(DR_SF12, DR_SF7), BAND_CENTI);  // g-band
  LMIC_setupChannel(3, 867100000, DR_RANGE_MAP(DR_SF12, DR_SF7), BAND_CENTI);  // g-band
  LMIC_setupChannel(4, 867300000, DR_RANGE_MAP(DR_SF12, DR_SF7), BAND_CENTI);  // g-band
  LMIC_setupChannel(5, 867500000, DR_RANGE_MAP(DR_SF12, DR_SF7), BAND_CENTI);  // g-band
  LMIC_setupChannel(6, 867700000, DR_RANGE_MAP(DR_SF12, DR_SF7), BAND_CENTI);  // g-band
  LMIC_setupChannel(7, 867900000, DR_RANGE_MAP(DR_SF12, DR_SF7), BAND_CENTI);  // g-band
  LMIC_setupChannel(8, 868800000, DR_RANGE_MAP(DR_FSK, DR_FSK), BAND_MILLI);   // g2-band
  LMIC_setLinkCheckMode(0);
  LMIC.dn2Dr = DR_SF9;
  LMIC_setDrTxpow(DR_SF7, 14);
  os_setTimedCallback(&sendjob, os_getTime() + sec2osticks(TX_INTERVAL), do_send);
}

void loop()
{
  read9dof();
  readGPS();
  readhumTemp();
  os_runloop_once();
}
void readGPS()
{
  while (GPSSerial.available() > 0)
    gps.encode(GPSSerial.read());
  if (gps.location.isUpdated())
  {
    Lat = gps.location.lat();
    Long = gps.location.lng();
  }
}
void readhumTemp()
{
  if (samplingInterval.isExpired() && !hih.isSampling())
  {
    hih.start();
    samplingInterval.repeat();
  }
  hih.process();
  if (hih.isFinished())
  {
    relativeHumidity = hih.getRelHumidity() / 100.0;
    Temperature = hih.getAmbientTemp() / 100.0;
    if (relativeHumidity < HumidityBoundary[0] || relativeHumidity > HumidityBoundary[1])
      IsHumidityOutOfBoundary = true;
    if (Temperature < TemperatureBoundary[0] || Temperature > TemperatureBoundary[1])
      IsTemperatureOutOfBoundary = true;
  }
}

void read9dof()
{
  readImu();
  if (calcTilted(imu.ax, imu.ay, imu.az, -imu.my, -imu.mx, imu.mz, tiltedBoundaryDegrees))
    IsTiltedOutOfBoundary = true;
  if (shockDetected())
  {
    // use this method "getGForce();" to send lora signal with this value
    ShockDetected = true;
    float gforce = getGForce();
    if (gforce > GForce)
      GForce = gforce;
  }
}

// returns true or false. true if 9dof stick is tilted over boundaryDegrees
bool calcTilted(float ax, float ay, float az, float mx, float my, float mz, float boundaryDegrees)
{
  float roll = atan2(ay, az);
  float pitch = atan2(-ax, sqrt(ay * ay + az * az));
  float heading;
  if (my == 0)
    heading = (mx < 0) ? PI : 0;
  else
    heading = atan2(mx, my);
  heading -= DECLINATION * PI / 180;
  if (heading > PI)
    heading -= (2 * PI);
  else if (heading < -PI)
    heading += (2 * PI);

  // Convert everything from radians to degrees:
  heading *= 180.0 / PI;
  pitch *= 180.0 / PI;
  roll *= 180.0 / PI;

  bool outOfBoundsRoll = (roll < boundaryDegrees && roll > boundaryDegrees * -1);
  bool outOfBoundsPitch = (pitch < boundaryDegrees && pitch > boundaryDegrees * -1);
  if (outOfBoundsRoll && outOfBoundsPitch)
    return true;
  return false;
}

bool shockDetected()
{
  float accel_z = getGForce();
  if (accel_z > 1.5 || accel_z < 0.5)
    return true;
  return false;
}

float getGForce()
{
  return imu.calcAccel(imu.az);
}

void readImu()
{
  if (imu.gyroAvailable())
    imu.readGyro();
  if (imu.accelAvailable())
    imu.readAccel();
  if (imu.magAvailable())
    imu.readMag();
}

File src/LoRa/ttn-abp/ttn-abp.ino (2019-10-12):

/*******************************************************************************
 * Copyright (c) 2015 Thomas Telkamp and Matthijs Kooijman
 *
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
 * This example sends a valid LoRaWAN packet with payload "Hello,
 * world!", using frequency and encryption settings matching those of
 * the The Things Network.
 *
 * This uses ABP (Activation-by-personalisation), where a DevAddr and
 * Session keys are preconfigured (unlike OTAA, where a DevEUI and
 * application key is configured, while the DevAddr and session keys are
 * assigned/generated in the over-the-air-activation procedure).
 *
 * Note: LoRaWAN per sub-band duty-cycle limitation is enforced (1% in
 * g1, 0.1% in g2), but not the TTN fair usage policy (which is probably
 * violated by this sketch when left running for longer)!
 *
 * To use this sketch, first register your application and device with
 * the things network, to set or generate a DevAddr, NwkSKey and
 * AppSKey. Each device should have their own unique values for these
 * fields.
 *
 * Do not forget to define the radio type correctly in config.h.
 *
 *******************************************************************************/

#include <lmic.h>
#include <hal/hal.h>
#include <SPI.h>

// LoRaWAN NwkSKey, network session key
// This is the default Semtech key, which is used by the early prototype TTN
// network.
static const PROGMEM u1_t NWKSKEY[16] = { 0x96, 0x74, 0x6C, 0x57, 0xD8, 0xE3, 0xB1, 0xD6, 0x3A, 0x04, 0x83, 0x04, 0xC4, 0x56, 0x8D, 0x36 };

// LoRaWAN AppSKey, application session key
// This is the default Semtech key, which is used by the early prototype TTN
// network.
static const u1_t PROGMEM APPSKEY[16] = { 0x1F, 0x42, 0x97, 0x73, 0xAE, 0xEA, 0xDA, 0xE8, 0xD4, 0xEE, 0x45, 0xF7, 0x54, 0xD4, 0xAE, 0x57 };

// LoRaWAN end-device address (DevAddr)
static const u4_t DEVADDR = 0x26011BFE ; // <-- Change this address for every node!

// These callbacks are only used in over-the-air activation, so they are
// left empty here (we cannot leave them out completely unless
// DISABLE_JOIN is set in config.h, otherwise the linker will complain).
void os_getArtEui (u1_t* buf) { }
void os_getDevEui (u1_t* buf) { }
void os_getDevKey (u1_t* buf) { }

static uint8_t mydata[] = "IMAD WAT!";
static osjob_t sendjob;

// Schedule TX every this many seconds (might become longer due to duty
// cycle limitations).
const unsigned TX_INTERVAL = 30;

// Pin mapping
const lmic_pinmap lmic_pins = {
    .nss = 6,
    .rxtx = LMIC_UNUSED_PIN,
    .rst = 7,
    .dio = {4, 5, LMIC_UNUSED_PIN}
};

void onEvent (ev_t ev) {
    Serial.print(os_getTime());
    Serial.print(": ");
    switch(ev) {
        case EV_SCAN_TIMEOUT:
            Serial.println(F("EV_SCAN_TIMEOUT"));
            break;
        case EV_BEACON_FOUND:
            Serial.println(F("EV_BEACON_FOUND"));
            break;
        case EV_BEACON_MISSED:
            Serial.println(F("EV_BEACON_MISSED"));
            break;
        case EV_BEACON_TRACKED:
            Serial.println(F("EV_BEACON_TRACKED"));
            break;
        case EV_JOINING:
            Serial.println(F("EV_JOINING"));
            break;
        case EV_JOINED:
            Serial.println(F("EV_JOINED"));
            break;
        case EV_RFU1:
            Serial.println(F("EV_RFU1"));
            break;
        case EV_JOIN_FAILED:
            Serial.println(F("EV_JOIN_FAILED"));
            break;
        case EV_REJOIN_FAILED:
            Serial.println(F("EV_REJOIN_FAILED"));
            break;
        case EV_TXCOMPLETE:
            Serial.println(F("EV_TXCOMPLETE (includes waiting for RX windows)"));
            if (LMIC.txrxFlags & TXRX_ACK)
              Serial.println(F("Received ack"));
            if (LMIC.dataLen) {
              Serial.println(F("Received "));
              Serial.println(LMIC.dataLen);
              Serial.println(F(" bytes of payload"));
            }
            // Schedule next transmission
            os_setTimedCallback(&sendjob, os_getTime()+sec2osticks(TX_INTERVAL), do_send);
            break;
        case EV_LOST_TSYNC:
            Serial.println(F("EV_LOST_TSYNC"));
            break;
        case EV_RESET:
            Serial.println(F("EV_RESET"));
            break;
        case EV_RXCOMPLETE:
            // data received in ping slot
            Serial.println(F("EV_RXCOMPLETE"));
            break;
        case EV_LINK_DEAD:
            Serial.println(F("EV_LINK_DEAD"));
            break;
        case EV_LINK_ALIVE:
            Serial.println(F("EV_LINK_ALIVE"));
            break;
         default:
            Serial.println(F("Unknown event"));
            break;
    }
}

void do_send(osjob_t* j){
    // Check if there is not a current TX/RX job running
    if (LMIC.opmode & OP_TXRXPEND) {
        Serial.println(F("OP_TXRXPEND, not sending"));
    } else {
        // Prepare upstream data transmission at the next possible time.
        LMIC_setTxData2(1, mydata, sizeof(mydata)-1, 0);
        Serial.println(F("Packet queued"));
    }
    // Next TX is scheduled after TX_COMPLETE event.
}
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

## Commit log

2019-09-20 added flowchart.png and flowchart image into analyse.md
2019-09-21 LMT87 temp sensor electrical specs added
2019-09-21 temperatuursensor argumentatie toegevoegd
2019-09-23 Power consumption
2019-09-23 Added atmel power consumption
2019-09-23 Changed the look of powerconsumption.md
2019-09-26 Template power consumption
2019-09-26 Update Power Consumption
2019-09-28 Added datasheet folder + 2 datasheets pdf format. Added electrical_scheme.md and explained the schematic
2019-09-28 flowchart doen
2019-09-28 Added pCB designs gps module, and explanation connections schemes
    [GPS_module.brd, GPS_module.sch]
2019-09-30 bill of materials
2019-09-30 added link to documentation, added link to bill of materials
2019-09-30 Added: Voltage regulator Datasheet Modified: electrical_scheme.pdf -> information about voltage regulate Deleted: Old datasheet voltage regulator
2019-09-30 Added eagle project with electrical scheme
    [electrical_scheme.sch]
2019-09-30 Changed electrical scheme + image
    [electrical_scheme.sch]
2019-09-30 updated pcb scheme, board and img
    [GPS.brd, GPS.sch, GPS_module.brd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]
2019-10-01 Added board, modified scheme grounds for ground plane
    [electrical_scheme.brd, electrical_scheme.sch]
2019-10-02 Deleted board + added reset circuit into scheme -> TODO: add smd switch into reset circuit
    [electrical_scheme.brd, electrical_scheme.sch]
2019-10-02 updated img
    [GPS_Module.sch, GPS_module.brd]
2019-10-02 Added GerberFiles and Automatic_backups
    deleted old img from board, changed lines to pcb, added ground plane
2019-10-03 Board scheme
    [electrical_scheme.brd, electrical_scheme.sch, untitled.brd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]
2019-10-03 Finished PCB, added gerber files
    [GPS_module.brd, GPS_module.sch, electrical_scheme.sch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]
2019-10-03 Optimized pcb design
    [mcu_module.brd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]
2019-10-03 Updated voltage regulator in specifaction table
2019-10-03 added humidity sensor scheme, board scheme, images and updated GPS module
    [GPS_Module.brd, GPS_Module.sch, hum_sens_test.brd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]
2019-10-04 Added 3d images of pcb
2019-10-04 Changed gerber files for export PCB
    [copper_top.gbr, drill_1_16.xln, gerber_job.gbrjob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]
2019-10-04 updated footprint, humidity sensor pcb, gps module pcb and images, added gerberfiles
    [GPS_Module.brd, humidity_sensor.brd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]
2019-10-07 Gerber files MCU v2, IMAGES MCU V2 added
    [mcu_module.brd, mcu_module.sch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]
2019-10-07 Updated gerber files
    [copper_top.gbr, drill_1_16.xln, gerber_job.gbrjob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]
2019-10-07 Added scheme lora module
    [lora_module.sch]
2019-10-07 added foot prints
2019-10-07 added footprints, updated gps scheme by adding antenna pin
2019-10-08 Added gerber files in folder
    [lora_module.brd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]
2019-10-11 Added ground to antenna scheme
    [lora_module.brd]
2019-10-11 Updated GPS Module, Footprints, Automatic backups
    [GPS_Module.sch, humidity_sensor.brd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]
2019-10-11 MCU PCB v3
    [mcu_module.brd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]
2019-10-11 CAM output files
    [copper_bottom.gbr, copper_top.gbr, drill_1_16.xln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]
2019-10-11 9Dof Acc + Gyro ok
2019-10-11 Added 3D m3
    [m3_spacers_5mm.stl]
2019-10-11 Gerber files
    [lora_module.brd, lora_module.sch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]
2019-10-11 Added bom file
    [bom.xlsx]
2019-10-11 Added templates
    [bom.xlsx]
2019-10-11 Added MCU and LoRa module PCB's components in BOM
    [bom.xlsx]
2019-10-11 bom gps and humidity
    [bom.xlsx]
2019-10-11 updated bom file
    [bom.xlsx]
2019-10-12 Changed the LoRa module layout for the connection with the mcu
    [copper_bottom.gbr, copper_top.gbr, drill_1_16.xln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]
2019-10-12 Updated PCB Image
    [lora_module.brd]
2019-10-12 Updated pins for LoRa module
    [copper_bottom.gbr, copper_top.gbr, drill_1_16.xln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]
2019-10-12 Added arduino code for transmitting a message over Lora TTN
2019-10-12 added lora antenna doc, mcu-lora code doc
2019-10-18 9dof final update
    [Testing.xlsx]
2019-10-25 added gps arduino code, added gps output
2019-12-08 Added Lasercut files and gerber outputs, also updates from mcu and lora module (jlcpcb modifications)
    [LaserCut_Jarno_MedicalDelivery2_v2.dxf, LaserCut_Jarno_MedicalDelivery2_v3.dxf, LaserCut_Jarno_MedicalDelivery2_v4.dxf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]
2019-12-12 Added SPI test
2019-12-16 Updated lora scheme
    [lora_module.brd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]
